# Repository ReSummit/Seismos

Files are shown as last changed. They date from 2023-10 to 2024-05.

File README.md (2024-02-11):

# Seismos

An evolution of the Zebra keyboard, but can be used for everyday typing. Switch between ortholinear for macro keypads and staggered for typing on the go.

Since this design utilizes daughter boards, you can even choose to move the columns around with a different rail system from the example one provided.

Allows for an interchangeable configuration between 4 and 5 row keys per column. With both halves of the keyboard, you can have a maximum of 68 keys (+2 encoder switches).

**NOTE:** If you had downloaded gerber files before December 5th, 2023, ***redownload*** the files as the RGB lights were not wired correctly. Apparently KiCAD displays the back side from the top perspective... doh! This is fixed. I also fixed the power switch so that sliding it up turns on the keyboard rather than this not being congruent on both sides.

## Pictures / Example Column Shifts:
<div style="display: flex; justify-content: center;">
    <figure>
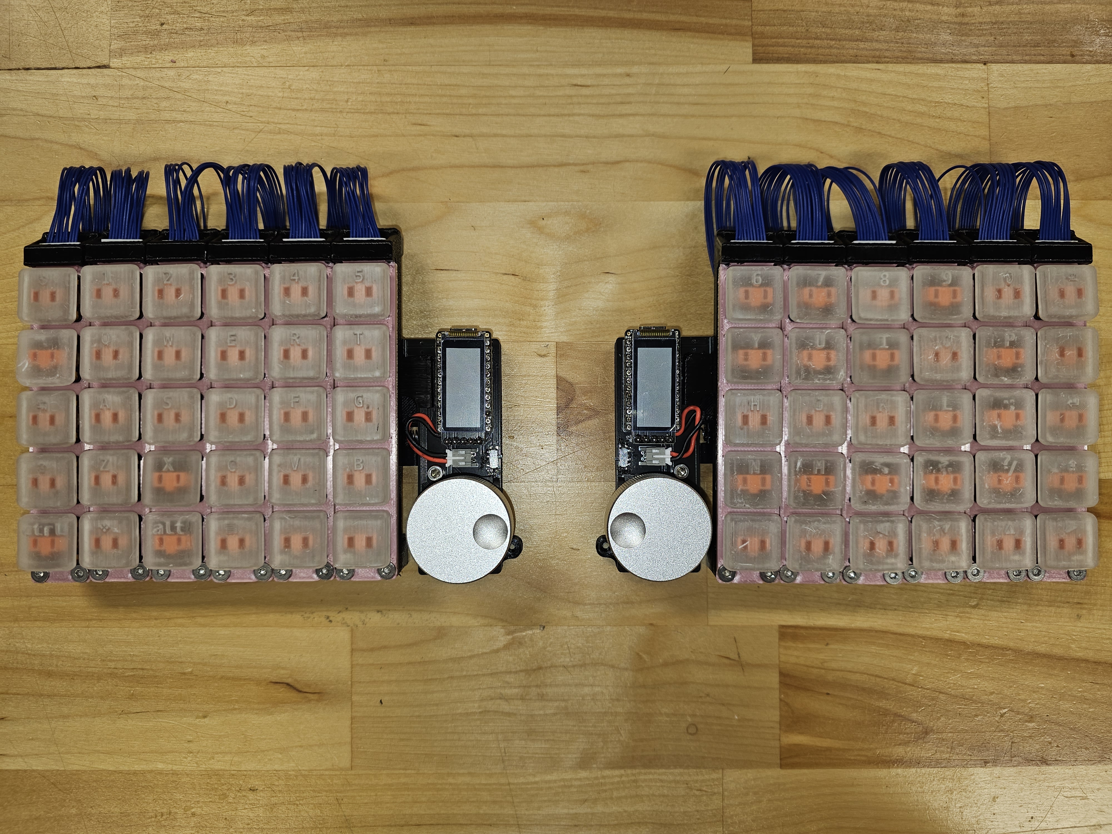
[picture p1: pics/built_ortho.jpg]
        
    </figure>
    <figure>
        
    </figure>
    <figure>
        
    </figure>
</div>

# PCB Library Structure

NOTE: If you check the PCB for DRC errors, most of them will come from either the keyboard_reversible.pretty footprint or the switch footprints inherited from the MiRage keyboard. Since both have been used before, they can be ignored.

## Libraries
All PCBs in the `pcbs` folder refer to the footprint and symbol libraries found in `libs/Seismos-libs` as well as `libs/keyboard_reversible.pretty`.

Wait, keyboard_reversible.pretty isn't in the git clone? You need to run git submodule initialization and update with this command:
```bash
git submodule update --init --recursive
```

After this, you should not get errors on missing libraries.

## Current State of PCBs
Since release v2.0.0, there are now PCBs that incorporate the 74HC595A shift register. Thanks to drFaustroll (from QMK Discord) on an example schematic for the shift register. With this shift register, displays are now on their own I2C / SPI bus and two pins are dedicated to split communications. 2 pins are now free so I have openned up these pins at the bottom of the keyboard on the front side. These ARE NOT compatible with the I2C variants of the keyboards unless you are not using the displays and will need some modification of the firmware, so choose carefully!

***WARNING***: If you are planning to use a display on this keyboard, note that nice!view compatibility with the I2C PCBs only applies for wireless builds only! Annoyingly, the nice!view does not use an ***I2C*** interface; it uses an ***SPI*** interface to work (***whyyyyyyy***). I considered moving the CS pin to the headphone jack, but this means that one of the hardware pins for I2C is not connected so this did not happen. Normal 4 pin I2C SSD1306 displays will work for wired or wireless builds however assuming that all communications happen on I2C.

There are column and thumb cluster layouts for 4 and 5 keys (however, thumb cluster can only have 4 max). This means you can get a max total of 68 keys, plus two if you are using the rotary encoders as buttons.

For this release, there are PCBs for 4 and 5 columns. Currently, the left, right, and columns are made with a maximum size of 7x5 keys per side. Something to know is that due to routing efficiency, the column order is reversed for the right side; however, row number remains the same from top to bottom.

With release v1.1.2, the PCBs are now fully tested and ready to be used. Still, read through the notes for building this keyboard a couple sections below so you know what you're getting into.

## PCB Design Thoughts
Theoretically, since JST SH connectors are pretty small, we can possibly a maximum of 12 pins, which means that you can get at most ~7 rows per column... if the microcontroller has that many pins!

Some future design thoughts:
* A suggestion to reduce pin count is to wire the 1x4 keys as a 2x2 key setup to save pins; however, this results in a 2x2n keyboard layout, which will likely be a pain... Still interesting though to point out.
* ZMK has a pull request that introduced charlieplexing, which will reduce the pin count. If this is done per half, it may be possible to have a 70% keyboard on both sides with 10 rows per column (5 forward diodes, 5 backwards diodes). There's quite a lot of room here but currently it is still in development.

# Important notes for building keyboard

For the JST SH cables, note that the male to male connector tips should face the same side. An example one is shown below (note it is a 9 pin JST SH cale, but should be the same for 10 pin JST cables).

Example of JST SH cable with male-to-male connectors facing the same side.
<div style="display: flex; justify-content: center;">
    <figure>
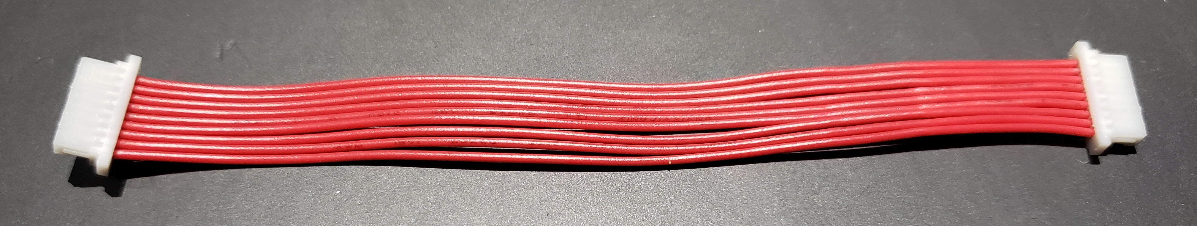
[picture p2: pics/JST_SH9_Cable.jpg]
        
    </figure>
</div>

Soldering the JST SH connectors is not easy! It is recommended to use the stencil design that is provided along with the stencil jig, hot plate, and solder paste. Otherwise, use a soldering iron and rely on flux!

After you are done building the core and mantle PCBs, there are example firmware files provided. Please checkout the `firmware_example` folder for more details. (Unfortunately, I haven't gotten to QMK yet, so that will have to wait for a bit)

# Required PCBs to upload

For PCBs, you will need the following:
* Minimum 2 core PCBs for left and right hands
* At least 14 mantle PCBs, 7 per core PCB
    * To save on cost, you may want to just stick with 20 of one type of mantle. 5 or 4 rows are usually enough

### **NOTE:** For the Core PCBs, you wil need to choose if you want I2C only or with a shift register starting from release v2.0.0. If you want to minimize components needed **and you are sure that you have an ATMEGA microcontroller**, you should choose I2C only. If you are not sure, you should choose I2C with shift register and just get the 74HC595A.

# BOM
## Required
* (**If using shift register version**) 2x 74HC595A SOIC-16 shift registers, though you may want extras just in case
* 28 x 10 position JST SH individual wires and connectors (preferrably 10cm long). Aliexpress has these with different colors like cable mods.
    * NOTE: For these links, they come from the same seller. Contact the seller after placing a temporary order to reduce shipping costs before paying!
    * Wires: https://www.aliexpress.us/item/3256802676433370.html (choose colors, **10 cm**, and **double head**)
        * For 5 rows, 10 cm is typically enough; you may be surprised at how far the columns can go with this. However, if you plan on changing the case design, you may need 15 cm if your columns need to go farther.
    * Connectors: https://www.aliexpress.us/item/3256802084257935.html (choose **10 pin** and **SMD Horizontal**)
* Parts that can be found from Typeractive.xyz:
    * 2 x EVQPUC02K reset button
    * 2 x SSSS811101 (alternatively on Aliexpress, MSK-12C01 or SW-12C01N-GY18)
    * 2 x 110 mAH battery (since TRRS does not have 5V, you need batteries; may change later)
* 2 x nice!nano (or Arduino Pro Micro compatible footprint)
* 56-70 x 1N4148W Diodes (variable number depending on how many keys you want)
* M3 assorted length screws (see case section for more details)
* 56-70 x MX / Choc PCB Sockets (1511 for MX or 1350 for Chocs)

## Optional
* 56-68 x SK6812MINI-E for RGB
    * 6 x per column from center of keyboard + 4 for each thumb cluster
        * Example: left and right sides require 80 total for all columns. If you only need 5 columns, then you need 68.
* 2 x nice!view (or OLED, but won't be aligned to center of microcontroller)
* 4 x 12 pin low profile socket pin headers for socketed microcontrollers (or similar)
* 2 x Rotary encoder EC11 (similar to Sofle)
* 2 x PJ320A headphone jacks 
    * **NOTE**: Due to me wanting to allow for wireless or wired setups, **the current PCB design will not charge the other keyboard side**. This is because VCC is disconnected to avoid blowing up the charging circuit of the nice!nano. If you need it, bridge the connector near one of the headphone jack pins.
* 2 x 4.7k SMD resistors for I2C. This is only needed if you plan on using I2C for split communications. There's not enough space for THT versions so uh sorry :(.

# Case
Curious to see what it looks like? Behold, OnShape link that contains questionable features that are unlabelled... This case works with the PCBs and allows for sliding rails, but won't lock the rails. A better design is in the works, but this is a good start.

Currently, a better design is in the works to place the rails underneath the PCB instead of above; this would allow the keyboard to be more low profile. For now, this works.

**This design requires the following additional parts:**
* Countersunk M3 screws:
    * 24 M3x12mm
        * Mounts down the PCB to each column plate frame into the bottom stopper
    * 3 M3x8mm
        * Holds down the rails for the keyboard
    * 14 M3x6mm
        * Corresponding nuts for the top stopper screws located near the top of each column needed
    * 2 M3x5mm
        * For the holes near the encoder and display

<p align="center">
    <p>Onshape Document (click on picture):</p>
    <a href="https://cad.onshape.com/documents/f7367bff9cd2cc9be8d2436b/w/1f753fadbcf1b9049e256121/e/c4b472236e977df85b7d8a49">
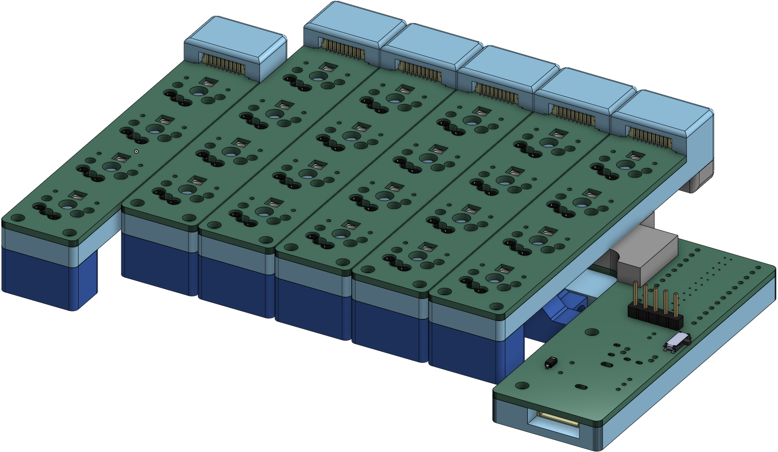
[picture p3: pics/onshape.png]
OnShape
        
    </a>
</p>

# More Pictures
<div style="display: flex; justify-content: center;">
    More pictures of build:
    <figure>
        
    </figure>
    <figure>
        
    </figure>
    Development case design:
    <figure>
        
    </figure>
    <figure>
        
    </figure>
</div>

# References

Seismos uses elements found from multiple places for footprints, symbols, and even the idea.

The idea for this keyboard was inspired from the [Zebra keyboard](https://github.com/nezumee/zebra). It uses jumper cables but looks to be mainly for having a physical means to determine the layout.

For footprints, they are derived from multiple places:
* [SnapEDA](https://snapeda.com) for initial 9 position JST SH footprints and models.
* [EasyEDA](https://easyeda.com) for the power switch, reset button, and 10 position JST SH footprints as well as some models.
* [Corne](https://github.com/foostan/crkbd) repository for the SK6812MINI-E footprint.
    * Fork from [petejohanson](https://github.com/petejohanson/crkbd/tree/board/corne-ultralight) for guide on nice!view pin connections.
* [Sofle](https://github.com/josefadamcik/SofleKeyboard) keyboard for rotary encoder and headphone jack footprints.
    * [Hayden Hu's PJ320A model](https://grabcad.com/library/pj320a-pj320d-3-5mm-jack-10) was used to show the headphone jack on the 3D viewer.
    * [Dmitry Levin's EC11 encoder models](https://grabcad.com/library/11mm-metal-shaft-rotary-encoders-tht-vertical-w-push-on-switch-1) was used to show the encoder on the 3D viewer.
* [keyboard_reversible.pretty](https://github.com/50an6xy06r6n/keyboard_reversible.pretty) for easy reverse footprints made for the Pro Micro.
* [Zack Freedman's MiRage Keyboard](https://github.com/ZackFreedman/MiRage) for Choc / MX footprints with modifications to include SK6812MINI-E within the footprint.
    * [Dennis Lee's Kailh 1350 socket model](https://grabcad.com/library/kailh-1350-socket-20) was used to show the switch socket on the 3D viewer.

In the libs folder, there may be other files regarding other footprints such as the EVQPUC02K. This was found on EasyEDA on early attempts to extract the footprints.
There is also the MSK-12C02 switch. This was found from [mzst's blog](https://mzstblog.blogspot.com/2016/01/msk-12c02-smd-slider-switch-spdt-eagle.html) website, which was a good reference for the switch, but I ended up using the symbol and combined with the other footprint found from EasyEDA. Archived here as well bvecause it is nice to have a backup of it.

For firmware, there are QMK, ZMK, and KMK. Only QMK has support for shift registers at the moment but I will get to the other firmwares at some point. QMK's firmware is somewhat based from the Sofle code already on the qmk_firmware, especially the oled implementation, which is untested. Also, the LICENSE may need to be updated; will check this later.

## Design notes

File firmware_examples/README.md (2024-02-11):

# Firmware files for Seismos
If you are finished with your PCB, congratulations! The PCBs are quite a challenge to do; I would know doing the PCBs twice at the moment...

**NOTE**: As of now, since the shift register was introduced in v2.0.0, only QMK has it configured. I will get to KMK and ZMK later but for now, they serve as an okay example for the column and keycode layout.

At this point, you can now flash your firmware to your Seismos. Here, you can find two firmware files for Seismos:
* KMK
    * KMK requires the normal setup for installing into your microcontroller. If you have chosen to use RGB, you will also need to import the neopixel library from adafruit into the `lib` folder. If you don't need this, remove the RGB sections from `main.py`. After that, you should be good to go with a basic layout.
* ZMK
    * ZMK requires a compilation of the firmware. Here, files are provided for a nice!nano v2 with a nice!view display. Follow the initialization steps to setup ZMK. Then copy the folder inside the zmk folder into `app/boards/shields`. You can then compile with the following code. If you have a zmk-config folder, use the flag `-DZMK_CONFIG="<zmk-config folder>"`:
```bash
west build --pristine -d build/seismosL -b nice_nano_v2 -- -DSHIELD="seismos_left nice_view_adapter nice_view"
cp build/seismosL/zephyr/zmk.uf2 ./seismosL.uf2

west build --pristine -d build/seismosR -b nice_nano_v2 -- -DSHIELD="seismos_right nice_view_adapter nice_view"
cp build/seismosR/zephyr/zmk.uf2 ./seismosR.uf2
```
    * Unfortunately, I haven't gotten to compile this for the RP2040. If you happen to get that working, do a pull request and I can take a look.
* QMK
    * QMK firmware uses some code from Sofle's QMK codebase, especially the oled (untested)
    * The current QMK firmware uploaded uses RP2040 conversion for the RP2040 board I have. If you have a pro micro, you can disable this conversion in the `rules.mk` file.

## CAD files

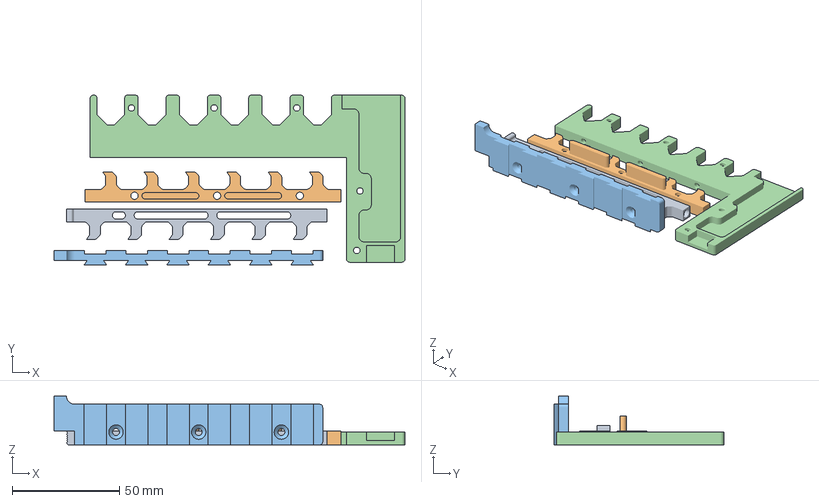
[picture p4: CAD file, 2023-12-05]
3dmodels/case/Mantle/Mantle.3mf
163.9 x 79.2 x 22.8 mm
Mantle - Part 4.stl
Mantle - Part 3.stl
Mantle - Part 2.stl
Mantle - Part 1.stl

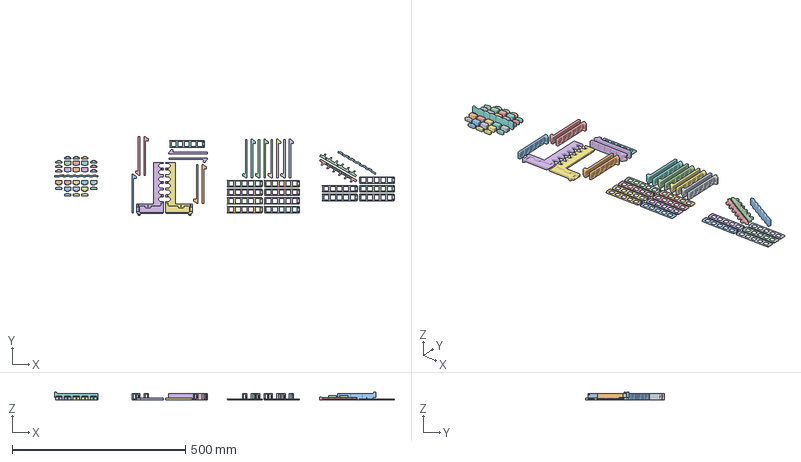
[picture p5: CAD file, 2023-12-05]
3dmodels/case/Plate/Plate_Mantle.3mf
981.2 x 229.0 x 22.8 mm
Plate - Part 4.stl
Plate - Part 2.stl
Plate - Part 3.stl
Plate - Part 1.stl
Plate Optimal
Mantle - Part 2.stl x 2
Mantle - Part 3.stl
Mantle - Part 4.stl
Mantle - Part 1.stl x 2

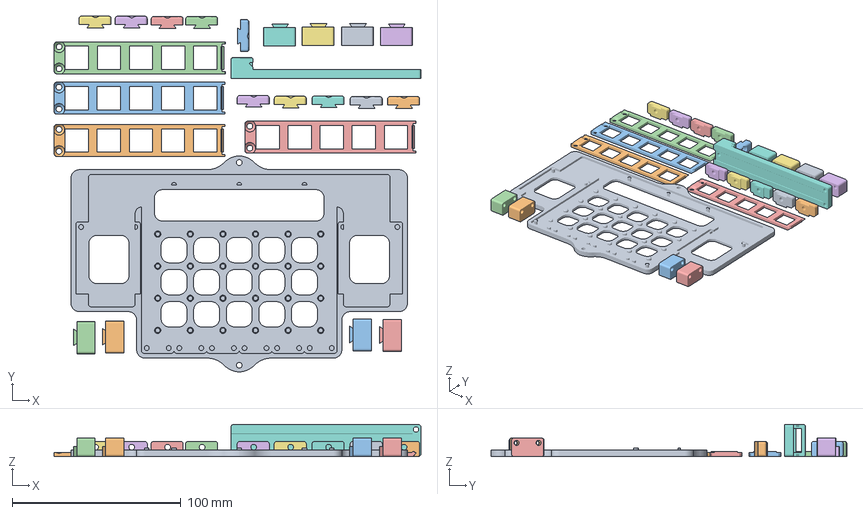
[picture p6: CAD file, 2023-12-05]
3dmodels/case/Stencil Jig - Part 1.3mf
217.2 x 210.7 x 19.0 mm
Stencil Jig - Part 1.stl
Plate - 5 Key - Part 4.stl
Plate - 5 Key - Part 3.stl
Plate - 5 Key - Part 2.stl
Plate - 5 Key - Part 1.stl

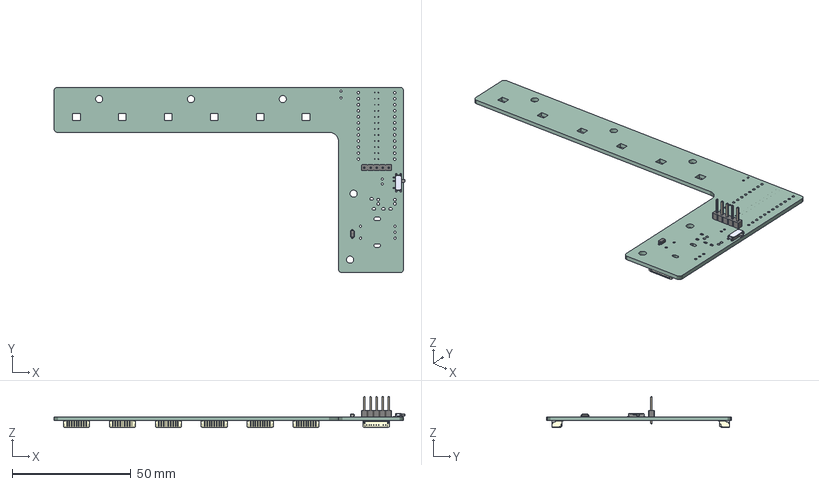
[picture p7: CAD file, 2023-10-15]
3dmodels/pcb/Seismos_CoreL.step
147.6 x 78.0 x 13.1 mm
Seismos_CoreL PCB

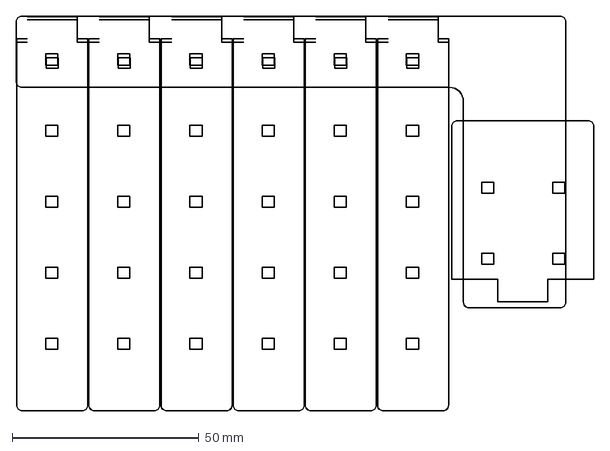
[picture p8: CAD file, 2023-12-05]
pcbs/Core PCBs (Mantles)/Stencil/Seismos_5CoreStencil/svg/Seismos_5CoreStencil-Edge_Cuts.dxf
154.5 x 105.5 mm

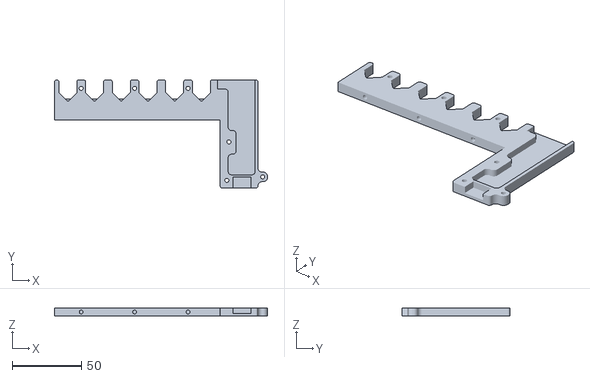
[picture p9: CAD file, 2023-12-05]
3dmodels/case/Mantle/Mantle - Part 1.stl
153.9 x 78.0 x 6.00

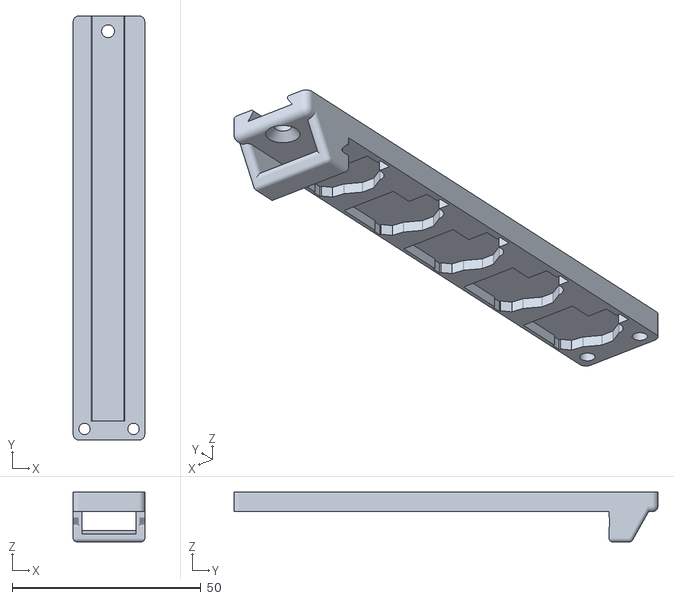
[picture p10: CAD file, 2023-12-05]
3dmodels/case/Plate/Plate - Part 1.stl
19.0 x 112.4 x 13.2

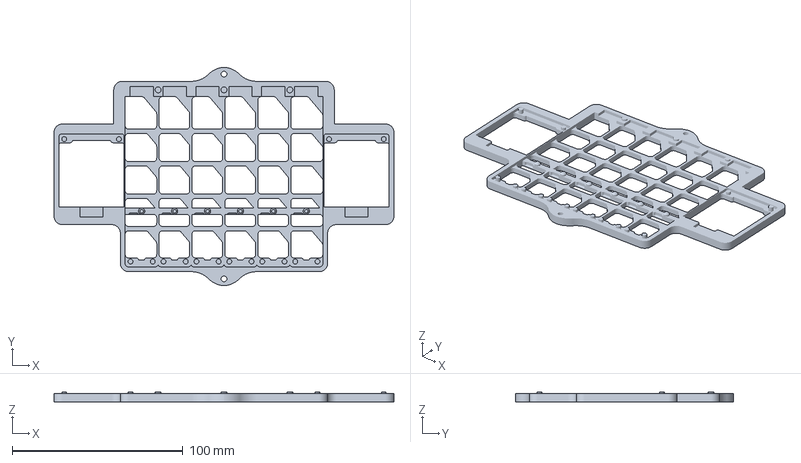
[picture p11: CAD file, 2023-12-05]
3dmodels/case/Stencil Jig Front - Part 1.3mf
199.2 x 128.0 x 6.00 mm

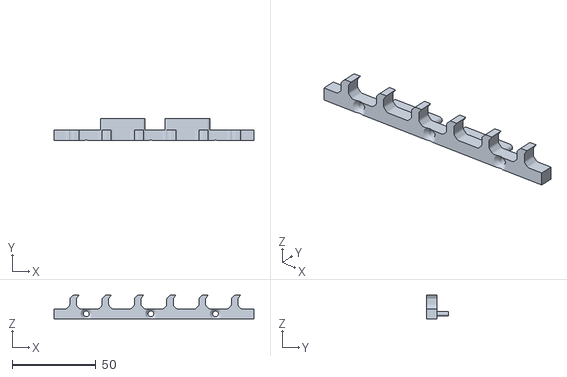
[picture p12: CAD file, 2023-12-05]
3dmodels/case/Mantle/Mantle - Part 3.stl
119.5 x 13.4 x 14.2

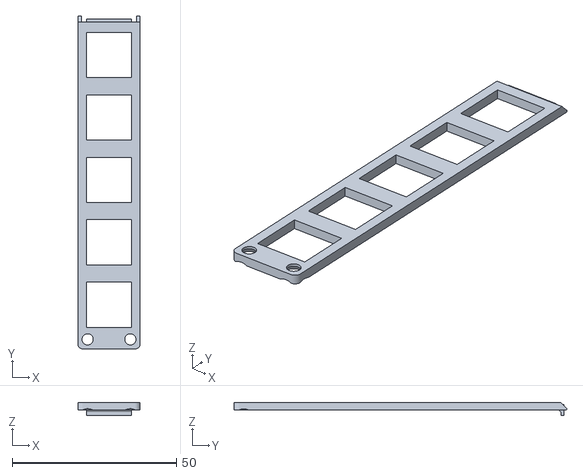
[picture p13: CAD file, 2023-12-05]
3dmodels/case/Plate/Plate - Part 4.stl
19.0 x 101.3 x 3.95

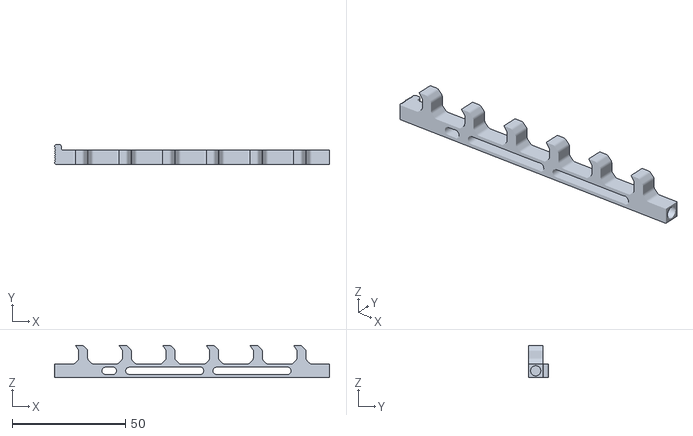
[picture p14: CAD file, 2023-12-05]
3dmodels/case/Mantle/Mantle - Part 4.stl
121.6 x 9.00 x 14.2

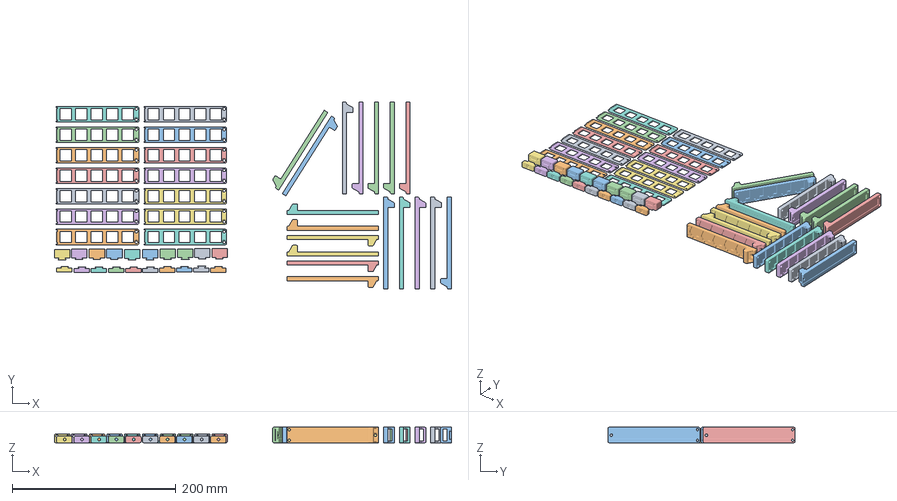
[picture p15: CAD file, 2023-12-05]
3dmodels/case/Plate/Plate.3mf
485.5 x 228.8 x 19.0 mm
Plate - Part 2.stl
Plate - Part 3.stl
Plate - Part 4.stl
Plate - Part 1.stl

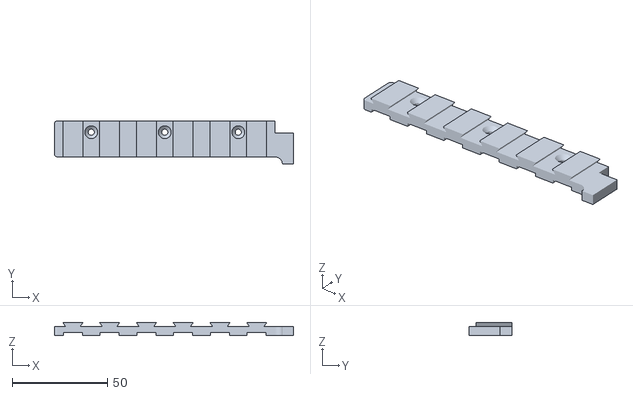
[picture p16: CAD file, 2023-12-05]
3dmodels/case/Mantle/Mantle - Part 2.stl
125.5 x 22.8 x 6.62

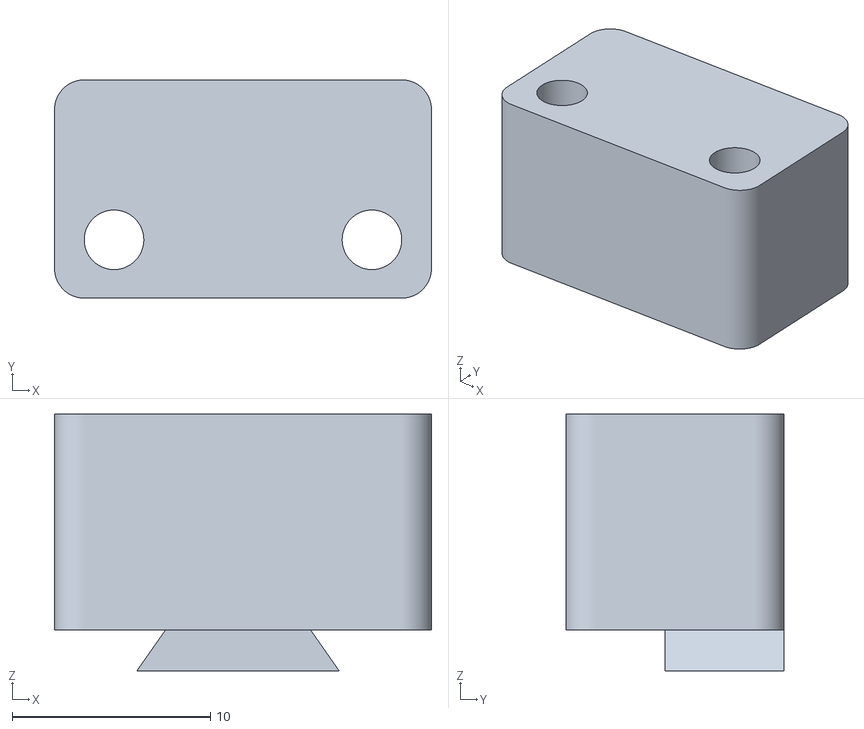
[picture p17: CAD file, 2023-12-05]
3dmodels/case/Plate/Plate - Part 3.stl
19.0 x 11.0 x 12.9

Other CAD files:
3dmodels/case/Plate/Plate_Rails.3mf
3dmodels/case/Plate/Plate - Part 2.stl
3dmodels/case/Stencil Jig - Part 1.stl
3dmodels/case/Stencil Jig Front - Part 1.stl
pcbs/Core PCBs (Mantles)/Stencil/Seismos_5CoreStencil/svg/Seismos_5CoreStencil-F_Mask.dxf
pcbs/Core PCBs (Mantles)/Stencil/Seismos_5CoreStencil/svg/Seismos_5CoreStencil-F_Paste.dxf

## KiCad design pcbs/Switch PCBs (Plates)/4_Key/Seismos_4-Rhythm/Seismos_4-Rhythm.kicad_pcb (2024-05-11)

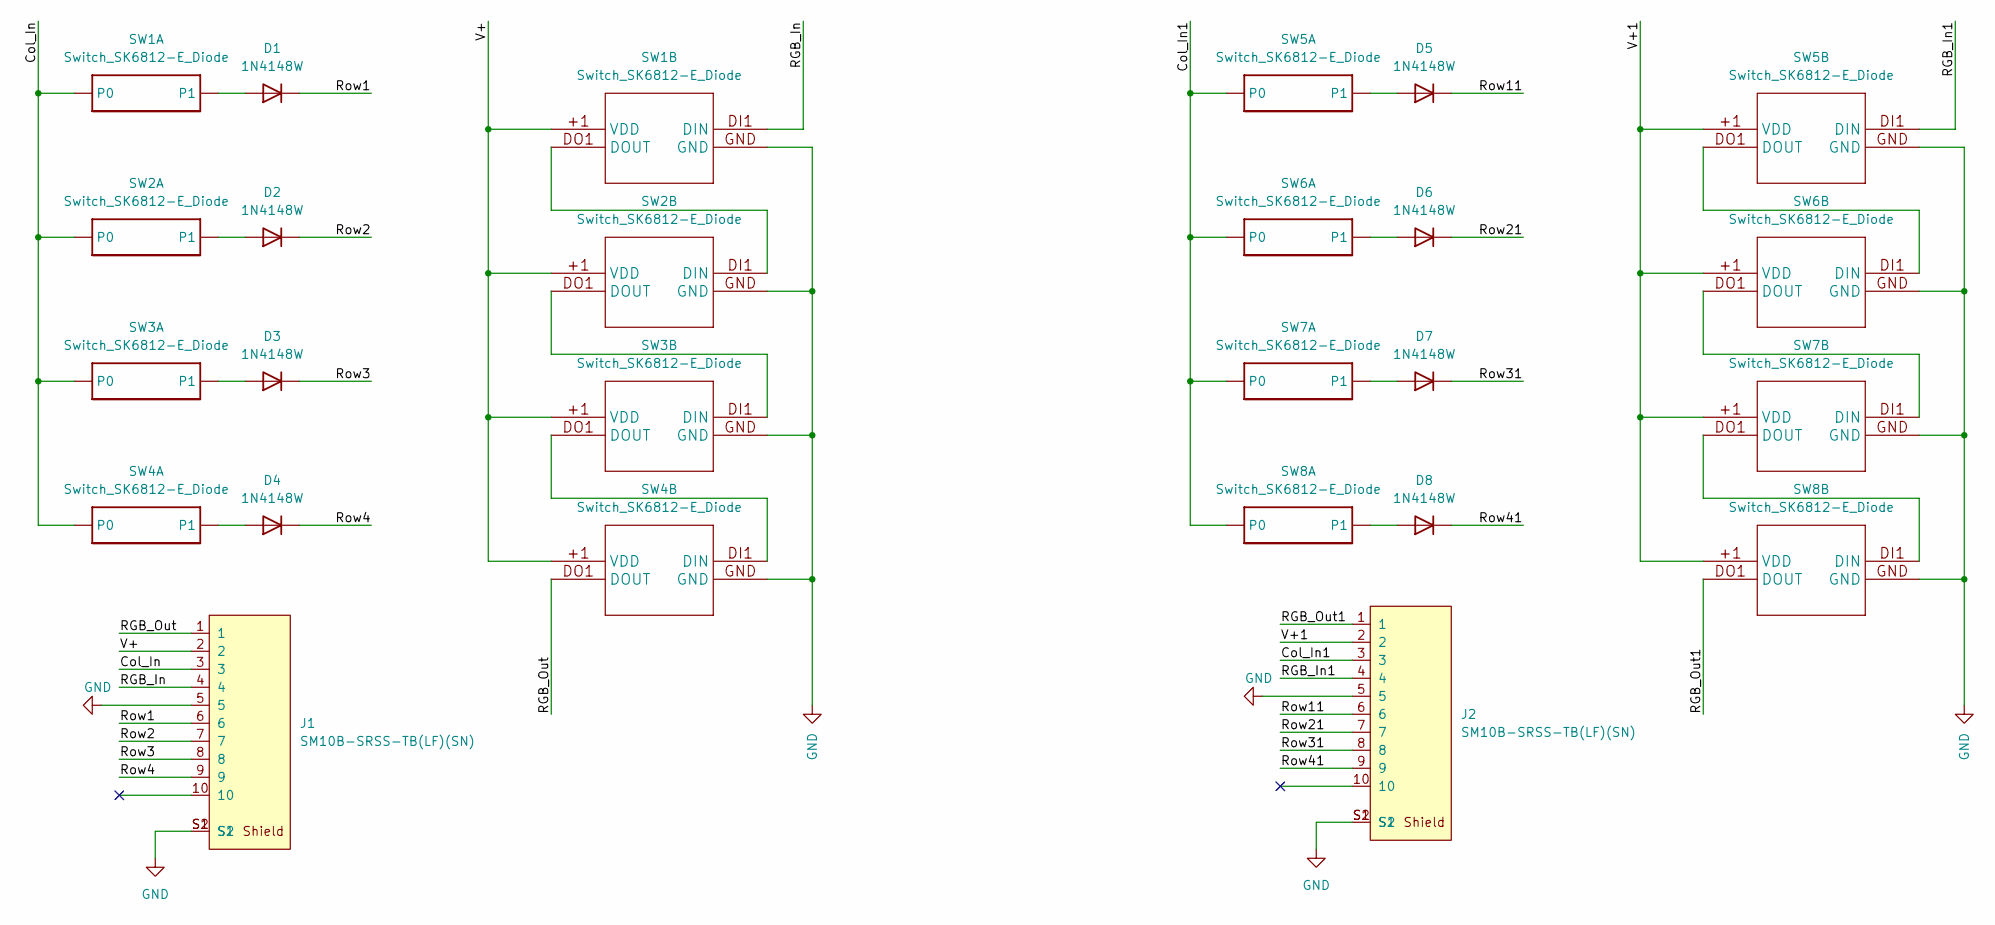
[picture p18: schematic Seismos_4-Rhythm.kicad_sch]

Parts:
D1, D2, D3, D4, D5, D6, D7, D8: 1N4148W; D_SOD-123
J1, J2: SM10B-SRSS-TB(LF)(SN); CONN-SMD_10P-P1.00_SM10B-SRSS-TB-LF-SN; PARTREV 1.0
SW1, SW2, SW3, SW4, SW5, SW6, SW7, SW8: Switch_SK6812-E_Diode

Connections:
/Col_In: J1.3, SW1.CHOC2 (P0), SW1.MX2 (P0), SW2.CHOC2 (P0), SW2.MX2 (P0), SW3.CHOC2 (P0), SW3.MX2 (P0), SW4.CHOC2 (P0), SW4.MX2 (P0)
/Col_In1: J2.3, SW5.CHOC2 (P0), SW5.MX2 (P0), SW6.CHOC2 (P0), SW6.MX2 (P0), SW7.CHOC2 (P0), SW7.MX2 (P0), SW8.CHOC2 (P0), SW8.MX2 (P0)
/RGB_In: J1.4, SW1.DI1 (DIN)
/RGB_In1: J2.4, SW5.DI1 (DIN)
/RGB_Out: J1.1, SW4.DO1 (DOUT)
/RGB_Out1: J2.1, SW8.DO1 (DOUT)
/Row1: D1.1 (K), J1.6
/Row2: D2.1 (K), J1.7
/Row3: D3.1 (K), J1.8
/Row4: D4.1 (K), J1.9
/Row11: D5.1 (K), J2.6
/Row21: D6.1 (K), J2.7
/Row31: D7.1 (K), J2.8
/Row41: D8.1 (K), J2.9
/V+: J1.2, SW1.+1 (VDD), SW2.+1 (VDD), SW3.+1 (VDD), SW4.+1 (VDD)
/V+1: J2.2, SW5.+1 (VDD), SW6.+1 (VDD), SW7.+1 (VDD), SW8.+1 (VDD)
GND: J1.5, J1.S1, J1.S2, J2.5, J2.S1, J2.S2, SW1.GND, SW2.GND, SW3.GND, SW4.GND, SW5.GND, SW6.GND, SW7.GND, SW8.GND
unnamed: D1.2 (A), SW1.CHOC1 (P1), SW1.MX1 (P1)
unnamed: D2.2 (A), SW2.CHOC1 (P1), SW2.MX1 (P1)
unnamed: D3.2 (A), SW3.CHOC1 (P1), SW3.MX1 (P1)
unnamed: D4.2 (A), SW4.CHOC1 (P1), SW4.MX1 (P1)
unnamed: D5.2 (A), SW5.CHOC1 (P1), SW5.MX1 (P1)
unnamed: D6.2 (A), SW6.CHOC1 (P1), SW6.MX1 (P1)
unnamed: D7.2 (A), SW7.CHOC1 (P1), SW7.MX1 (P1)
unnamed: D8.2 (A), SW8.CHOC1 (P1), SW8.MX1 (P1)
unnamed: SW1.DO1 (DOUT), SW2.DI1 (DIN)
unnamed: SW2.DO1 (DOUT), SW3.DI1 (DIN)
unnamed: SW3.DO1 (DOUT), SW4.DI1 (DIN)
unnamed: SW5.DO1 (DOUT), SW6.DI1 (DIN)
unnamed: SW6.DO1 (DOUT), SW7.DI1 (DIN)
unnamed: SW7.DO1 (DOUT), SW8.DI1 (DIN)

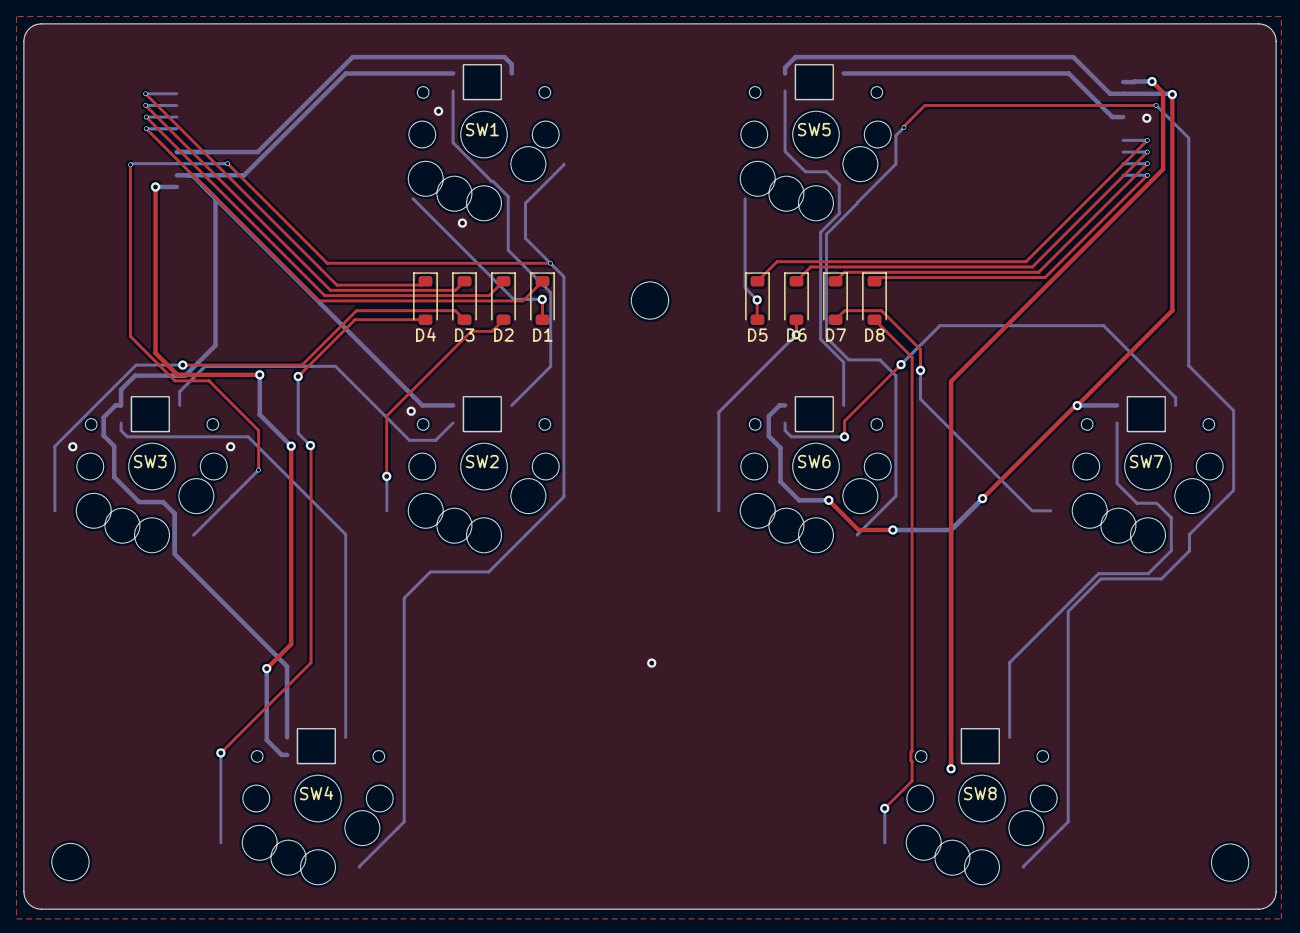
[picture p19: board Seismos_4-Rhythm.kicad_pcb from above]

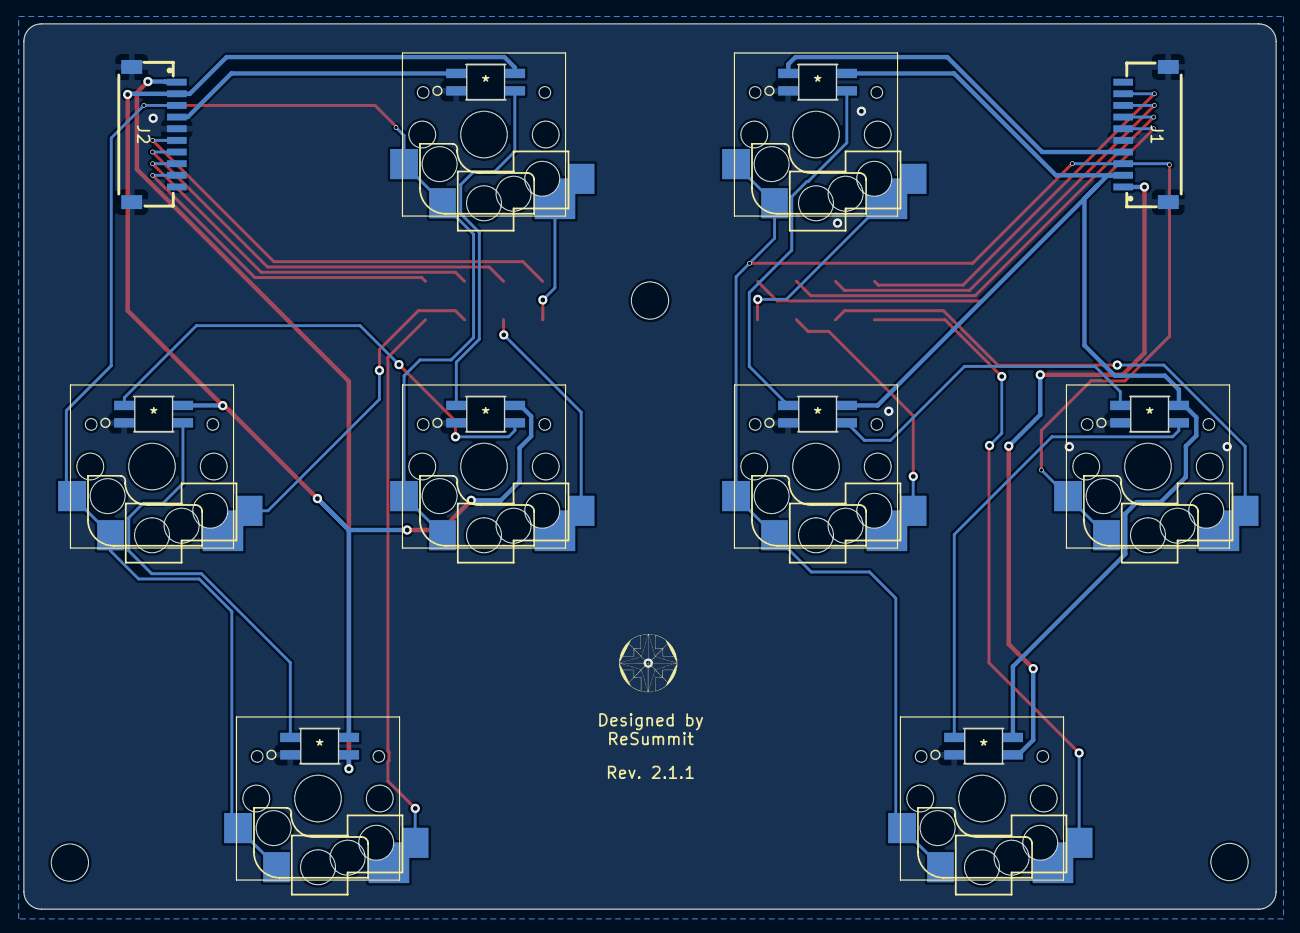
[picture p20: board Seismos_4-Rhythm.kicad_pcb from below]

Board: 2 copper layers, 107.5 x 76.0 mm, 18 parts (10 on the bottom side), 31 nets.

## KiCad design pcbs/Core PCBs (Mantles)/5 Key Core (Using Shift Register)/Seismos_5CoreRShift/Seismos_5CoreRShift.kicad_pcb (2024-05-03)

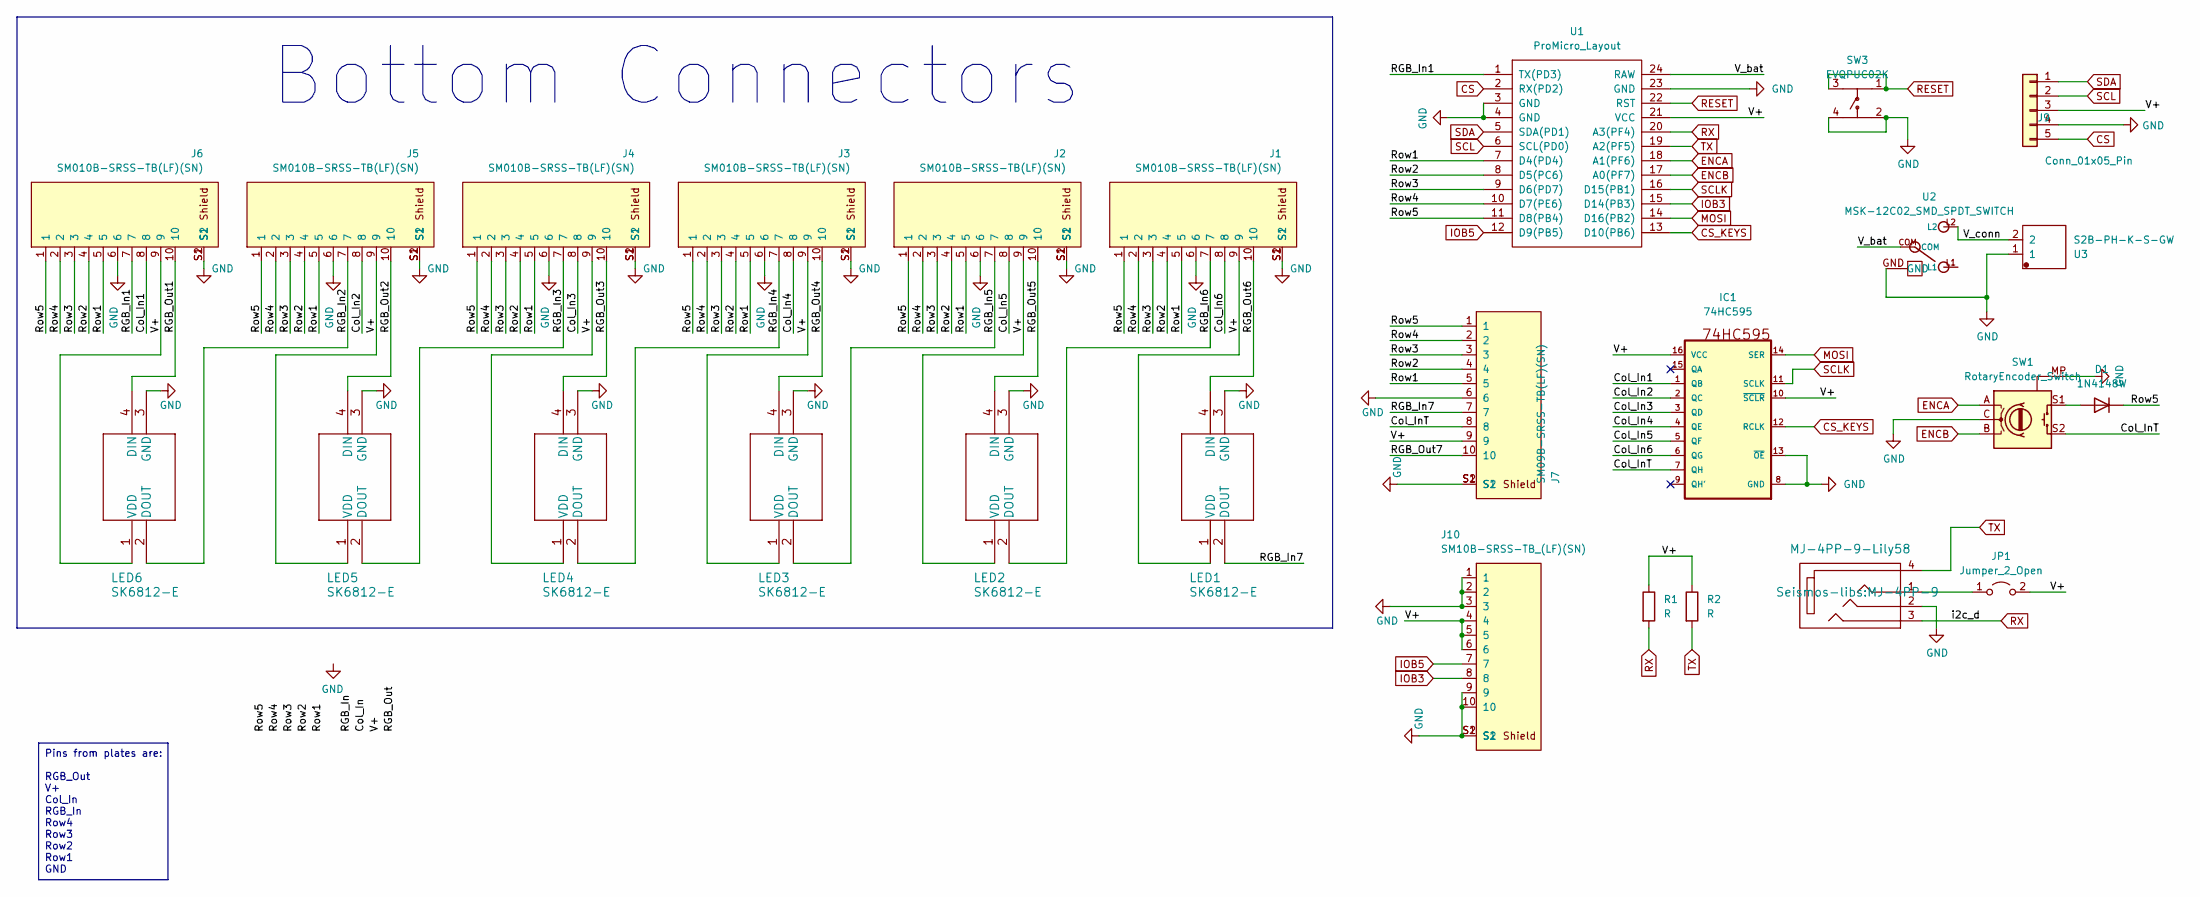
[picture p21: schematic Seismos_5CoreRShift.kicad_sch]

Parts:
D1: 1N4148W; D_SOD-123
IC1: 74HC595; SO16
J1, J2, J3, J4, J5, J6: SM010B-SRSS-TB(LF)(SN); CONN-SMD_10P-P1.00_SM10B-SRSS-TB-LF-SN; PARTREV 1.0
J7: SM09B-SRSS-TB(LF)(SN); CONN-SMD_10P-P1.00_SM10B-SRSS-TB-LF-SN; PARTREV 1.0
J8: MJ-4PP-9-Lily58; MJ-4PP-9
J9: Conn_01x05_Pin; PinHeader_1x05_P2.54mm_Vertical
J10: SM10B-SRSS-TB_(LF)(SN); CONN-SMD_10P-P1.00_SM10B-SRSS-TB-LF-SN; PARTREV 1.0
JP1: Jumper_2_Open; SolderJumper-2_P1.3mm_Open_TrianglePad1.0x1.5mm
LED1, LED2, LED3, LED4, LED5, LED6: SK6812-E
R1, R2: R; R_0603_1608Metric_Pad0.98x0.95mm_HandSolder
SW1: RotaryEncoder_Switch; RotaryEncoder_Alps_EC11E-Switch_Vertical_H20mm-keebio_modif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
SW3: EVQPUC02K; SW-SMD_EVQPUD02K
U1: ProMicro_Layout; keebRev-onesided_ProMicro
U2: MSK-12C02_SMD_SPDT_SWITCH; SW_PCM12SMTR
U3: S2B-PH-K-S-GW; CONN-TH_S2B-PH-K-S-GW

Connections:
/Col_In1: IC1.1 (QB), J6.8
/Col_In2: IC1.2 (QC), J5.8
/Col_In3: IC1.3 (QD), J4.8
/Col_In4: IC1.4 (QE), J3.8
/Col_In5: IC1.5 (QF), J2.8
/Col_In6: IC1.6 (QG), J1.8
/Col_InT: IC1.7 (QH), J7.8, SW1.S2
/RGB_In1: J6.7, U1.1 (TX(PD3))
/RGB_In2: J5.7, LED6.2 (DOUT)
/RGB_In3: J4.7, LED5.2 (DOUT)
/RGB_In4: J3.7, LED4.2 (DOUT)
/RGB_In5: J2.7, LED3.2 (DOUT)
/RGB_In6: J1.7, LED2.2 (DOUT)
/RGB_In7: J7.7, LED1.2 (DOUT)
/RGB_Out1: J6.10, LED6.4 (DIN)
/RGB_Out2: J5.10, LED5.4 (DIN)
/RGB_Out3: J4.10, LED4.4 (DIN)
/RGB_Out4: J3.10, LED3.4 (DIN)
/RGB_Out5: J2.10, LED2.4 (DIN)
/RGB_Out6: J1.10, LED1.4 (DIN)
/RGB_Out7: J7.10
/Row1: J1.5, J2.5, J3.5, J4.5, J5.5, J6.5, J7.5, U1.7 (D4(PD4))
/Row2: J1.4, J2.4, J3.4, J4.4, J5.4, J6.4, J7.4, U1.8 (D5(PC6))
/Row3: J1.3, J2.3, J3.3, J4.3, J5.3, J6.3, J7.3, U1.9 (D6(PD7))
/Row4: J1.2, J2.2, J3.2, J4.2, J5.2, J6.2, J7.2, U1.10 (D7(PE6))
/Row5: D1.1 (K), J1.1, J2.1, J3.1, J4.1, J5.1, J6.1, J7.1, U1.11 (D8(PB4))
/V+: IC1.10 (~SCLR), IC1.16 (VCC), J1.9, J2.9, J3.9, J4.9, J5.9, J6.9, J7.9, J9.3, J10.4, J10.5, J10.6, JP1.2 (B), LED1.1 (VDD), LED2.1 (VDD), LED3.1 (VDD), LED4.1 (VDD), LED5.1 (VDD), LED6.1 (VDD), R1.1, R2.1, U1.21 (VCC)
/V_bat: U1.24 (RAW), U2.COM
/V_conn: U2.L2, U3.2
CS: J9.5, U1.2 (RX(PD2))
CS_KEYS: IC1.12 (RCLK), U1.13 (D10(PB6))
ENCA: SW1.A, U1.18 (A1(PF6))
ENCB: SW1.B, U1.17 (A0(PF7))
GND: IC1.8 (GND), IC1.13 (~OE), J1.6, J1.S1, J1.S2, J2.6, J2.S1, J2.S2, J3.6, J3.S1, J3.S2, J4.6, J4.S1, J4.S2, J5.6, J5.S1, J5.S2, J6.6, J6.S1, J6.S2, J7.6, J7.S1, J7.S2, J8.2, J9.4, J10.1, J10.2, J10.3, J10.9, J10.10, J10.S1, J10.S2, LED1.3 (GND), LED2.3 (GND), LED3.3 (GND), LED4.3 (GND), LED5.3 (GND), LED6.3 (GND), SW1.C, SW1.MP, SW3.2, SW3.4, U1.3 (GND), U1.4 (GND), U1.23 (GND), U2.GND, U3.1
IOB3: J10.8, U1.15 (D14(PB3))
IOB5: J10.7, U1.12 (D9(PB5))
MOSI: IC1.14 (SER), U1.14 (D16(PB2))
unnamed: D1.2 (A), SW1.S1
unnamed: J8.1, JP1.1 (A)
RESET: SW3.1, SW3.3, U1.22 (RST)
RX: J8.3, R1.2, U1.20 (A3(PF4))
SCL: J9.2, U1.6 (SCL(PD0))
SCLK: IC1.11 (SCLK), U1.16 (D15(PB1))
SDA: J9.1, U1.5 (SDA(PD1))
TX: J8.4, R2.2, U1.19 (A2(PF5))

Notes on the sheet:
Pins from plates are: RGB_Out V+ Col_In RGB_In Row4 Row3 Row2 Row1 GND
Bottom Connectors

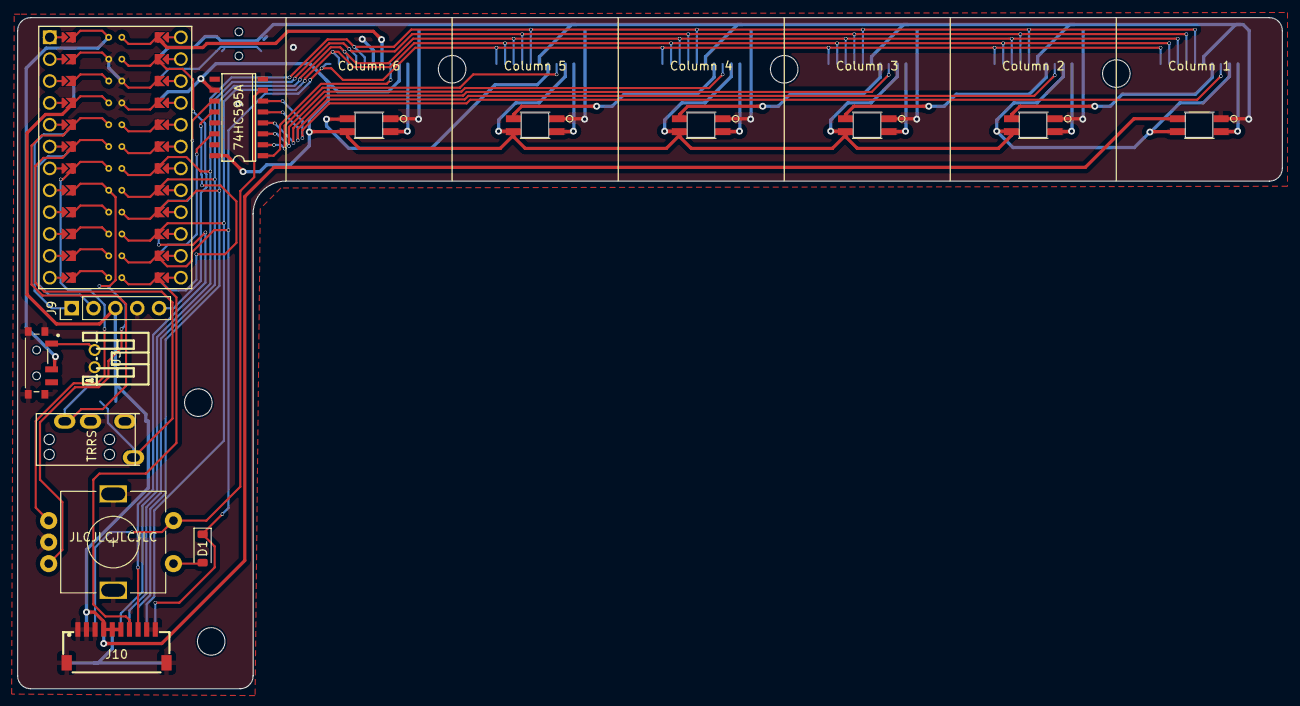
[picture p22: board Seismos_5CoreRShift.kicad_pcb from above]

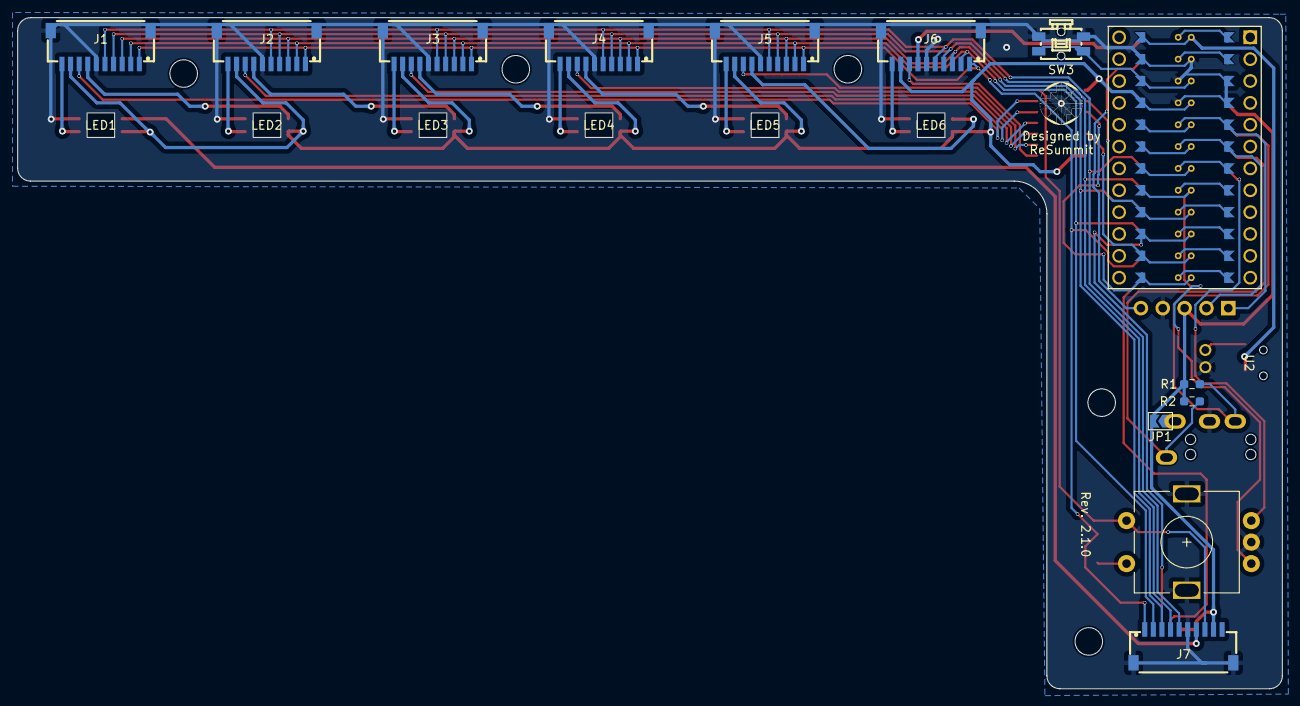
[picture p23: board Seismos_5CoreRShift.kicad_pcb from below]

Board: 2 copper layers, 147.0 x 78.0 mm, 26 parts (11 on the bottom side), 44 nets.

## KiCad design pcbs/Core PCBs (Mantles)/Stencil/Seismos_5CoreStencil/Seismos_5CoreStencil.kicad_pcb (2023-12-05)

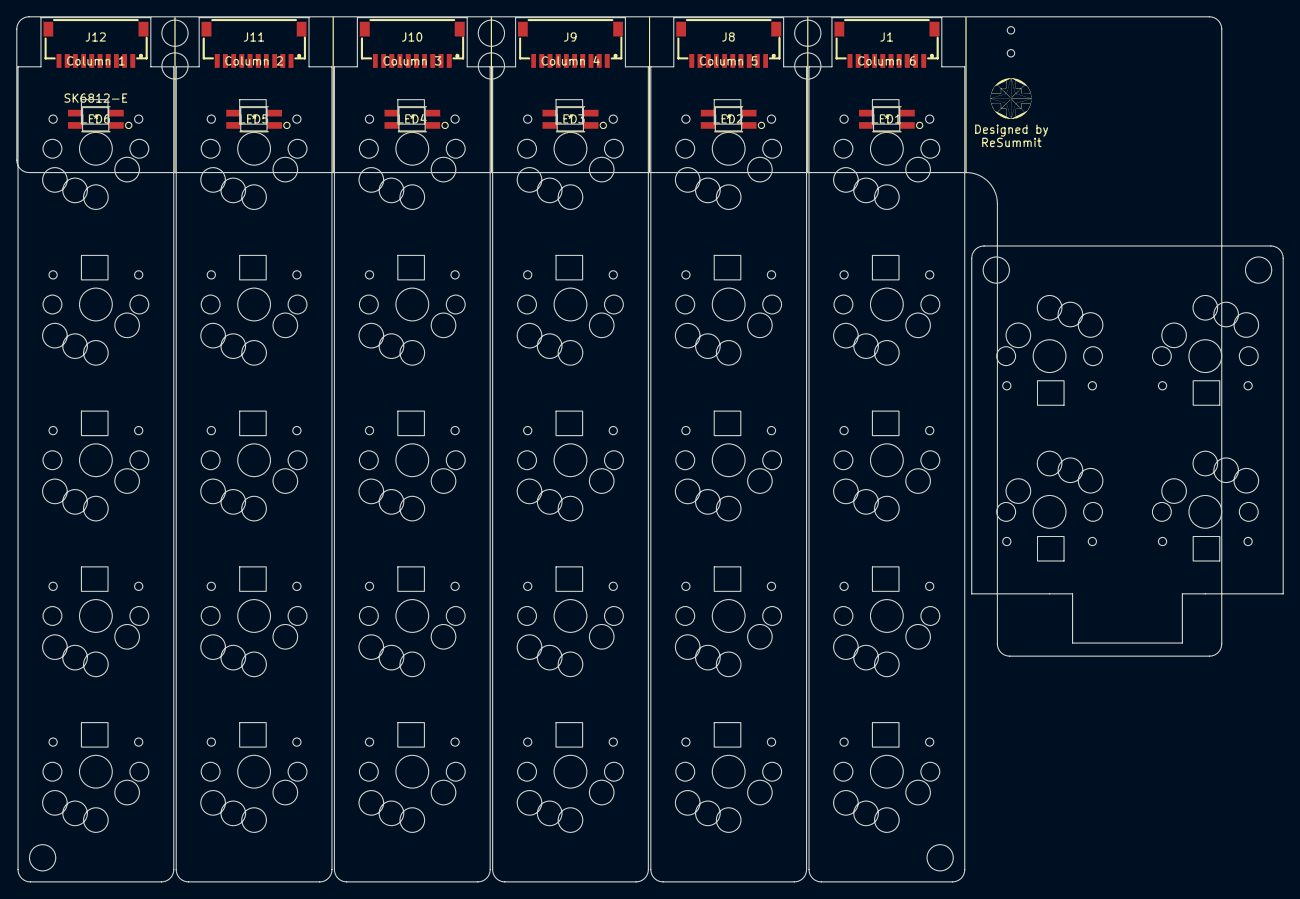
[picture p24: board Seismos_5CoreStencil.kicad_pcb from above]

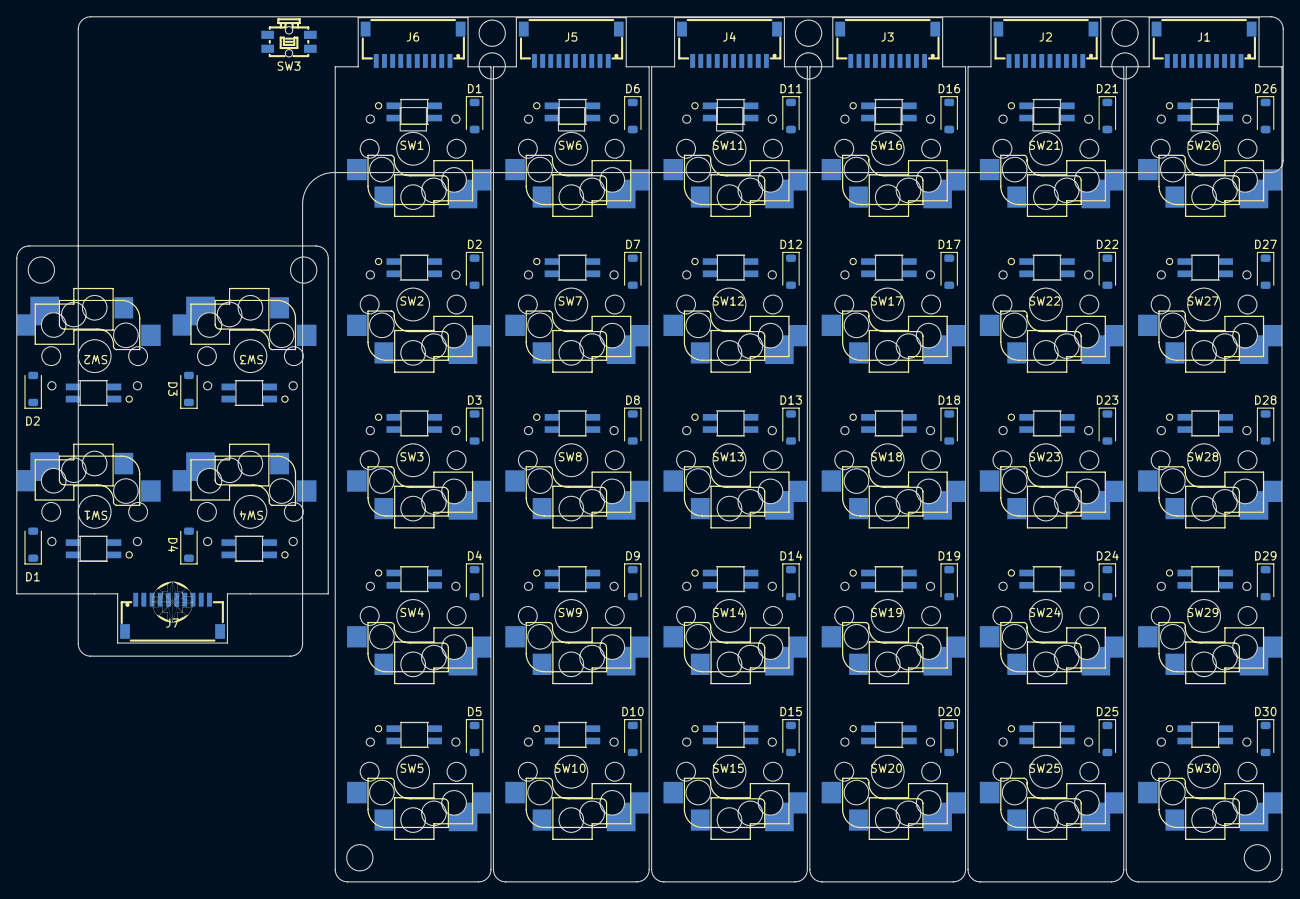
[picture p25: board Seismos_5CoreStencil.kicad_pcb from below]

Board: 2 copper layers, 154.5 x 105.5 mm, 91 parts (82 on the bottom side), 20 nets, no tracks yet.

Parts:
2, 4, 4#2: Hole_M3_3.2mm
D1, D1#2, D2, D2#2, D3, D3#2, D4, D4#2, D5, D6, D7, D8, D9, D10, D11, D12, D13, D14, D15, D16, D17, D18, D19, D20, D21, D22, D23, D24, D25, D26, D27, D28, D29, D30: 1N4148W; D_SOD-123
J1, J8, J9, J10, J11, J12: SM10B-SRSS-TB_(LF)(SN); CONN-SMD_10P-P1.00_SM10B-SRSS-TB-LF-SN
J1#2, J2, J3, J4, J5, J6, J7: SM09B-SRSS-TB(LF)(SN); CONN-SMD_10P-P1.00_SM10B-SRSS-TB-LF-SN
LED1, LED2, LED3, LED4, LED5, LED6: SK6812-E
SW1, SW1#2, SW2, SW2#2, SW3, SW3#3, SW4, SW4#2, SW5, SW6, SW7, SW8, SW9, SW10, SW11, SW12, SW13, SW14, SW15, SW16, SW17, SW18, SW19, SW20, SW21, SW22, SW23, SW24, SW25, SW26, SW27, SW28, SW29, SW30: Switch_SK6812-E_Diode
SW3#2: EVQPUC02K; SW-SMD_EVQPUD02K

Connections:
/RGB_In2: J5.7, LED1.2 (DOUT)
/RGB_In3: J4.7, LED2.2 (DOUT)
/RGB_In4: J3.7, LED3.2 (DOUT)
/RGB_In5: J2.7, LED4.2 (DOUT)
/RGB_In6: J1#2.7, LED5.2 (DOUT)
/RGB_In7: J7.7, LED6.2 (DOUT)
/RGB_Out1: J6.10, LED1.4 (DIN)
/RGB_Out2: J5.10, LED2.4 (DIN)
/RGB_Out3: J4.10, LED3.4 (DIN)
/RGB_Out4: J3.10, LED4.4 (DIN)
/RGB_Out5: J2.10, LED5.4 (DIN)
/RGB_Out6: J1#2.10, LED6.4 (DIN)
/Row1: D1.1 (K), D1#2.1 (K), D6.1 (K), D11.1 (K), D16.1 (K), D21.1 (K), D26.1 (K), J1.6, J1#2.5, J2.5, J3.5, J4.5, J5.5, J6.5, J7.5, J8.6, J9.6, J10.6, J11.6, J12.6
/Row2: D2.1 (K), D2#2.1 (K), D7.1 (K), D12.1 (K), D17.1 (K), D22.1 (K), D27.1 (K), J1.7, J1#2.4, J2.4, J3.4, J4.4, J5.4, J6.4, J7.4, J8.7, J9.7, J10.7, J11.7, J12.7
/Row3: D3.1 (K), D3#2.1 (K), D8.1 (K), D13.1 (K), D18.1 (K), D23.1 (K), D28.1 (K), J1.8, J1#2.3, J2.3, J3.3, J4.3, J5.3, J6.3, J7.3, J8.8, J9.8, J10.8, J11.8, J12.8
/Row4: D4.1 (K), D4#2.1 (K), D9.1 (K), D14.1 (K), D19.1 (K), D24.1 (K), D29.1 (K), J1.9, J1#2.2, J2.2, J3.2, J4.2, J5.2, J6.2, J7.2, J8.9, J9.9, J10.9, J11.9, J12.9
/Row5: D5.1 (K), D10.1 (K), D15.1 (K), D20.1 (K), D25.1 (K), D30.1 (K), J1.10, J1#2.1, J2.1, J3.1, J4.1, J5.1, J6.1, J8.10, J9.10, J10.10, J11.10, J12.10
/V+: J1.2, J1#2.9, J2.9, J3.9, J4.9, J5.9, J6.9, J7.9, J8.2, J9.2, J10.2, J11.2, J12.2, LED1.1 (VDD), LED2.1 (VDD), LED3.1 (VDD), LED4.1 (VDD), LED5.1 (VDD), LED6.1 (VDD), SW1.+1 (VDD), SW1#2.+1 (VDD), SW2.+1 (VDD), SW2#2.+1 (VDD), SW3.+1 (VDD), SW3#3.+1 (VDD), SW4.+1 (VDD), SW4#2.+1 (VDD), SW5.+1 (VDD), SW6.+1 (VDD), SW7.+1 (VDD), SW8.+1 (VDD), SW9.+1 (VDD), SW10.+1 (VDD), SW11.+1 (VDD), SW12.+1 (VDD), SW13.+1 (VDD), SW14.+1 (VDD), SW15.+1 (VDD), SW16.+1 (VDD), SW17.+1 (VDD), SW18.+1 (VDD), SW19.+1 (VDD), SW20.+1 (VDD), SW21.+1 (VDD), SW22.+1 (VDD), SW23.+1 (VDD), SW24.+1 (VDD), SW25.+1 (VDD), SW26.+1 (VDD), SW27.+1 (VDD), SW28.+1 (VDD), SW29.+1 (VDD), SW30.+1 (VDD)
GND: J1.5, J1.S1, J1.S2, J1#2.6, J1#2.S1, J1#2.S2, J2.6, J2.S1, J2.S2, J3.6, J3.S1, J3.S2, J4.6, J4.S1, J4.S2, J5.6, J5.S1, J5.S2, J6.6, J6.S1, J6.S2, J7.6, J7.S1, J7.S2, J8.5, J8.S1, J8.S2, J9.5, J9.S1, J9.S2, J10.5, J10.S1, J10.S2, J11.5, J11.S1, J11.S2, J12.5, J12.S1, J12.S2, LED1.3 (GND), LED2.3 (GND), LED3.3 (GND), LED4.3 (GND), LED5.3 (GND), LED6.3 (GND), SW1.GND, SW1#2.GND, SW2.GND, SW2#2.GND, SW3.GND, SW3#2.2, SW3#2.4, SW3#3.GND, SW4.GND, SW4#2.GND, SW6.GND, SW7.GND, SW8.GND, SW9.GND, SW11.GND, SW12.GND, SW13.GND, SW14.GND, SW16.GND, SW17.GND, SW18.GND, SW19.GND, SW21.GND, SW22.GND, SW23.GND, SW24.GND, SW26.GND, SW27.GND, SW28.GND, SW29.GND
RESET: SW3#2.1, SW3#2.3

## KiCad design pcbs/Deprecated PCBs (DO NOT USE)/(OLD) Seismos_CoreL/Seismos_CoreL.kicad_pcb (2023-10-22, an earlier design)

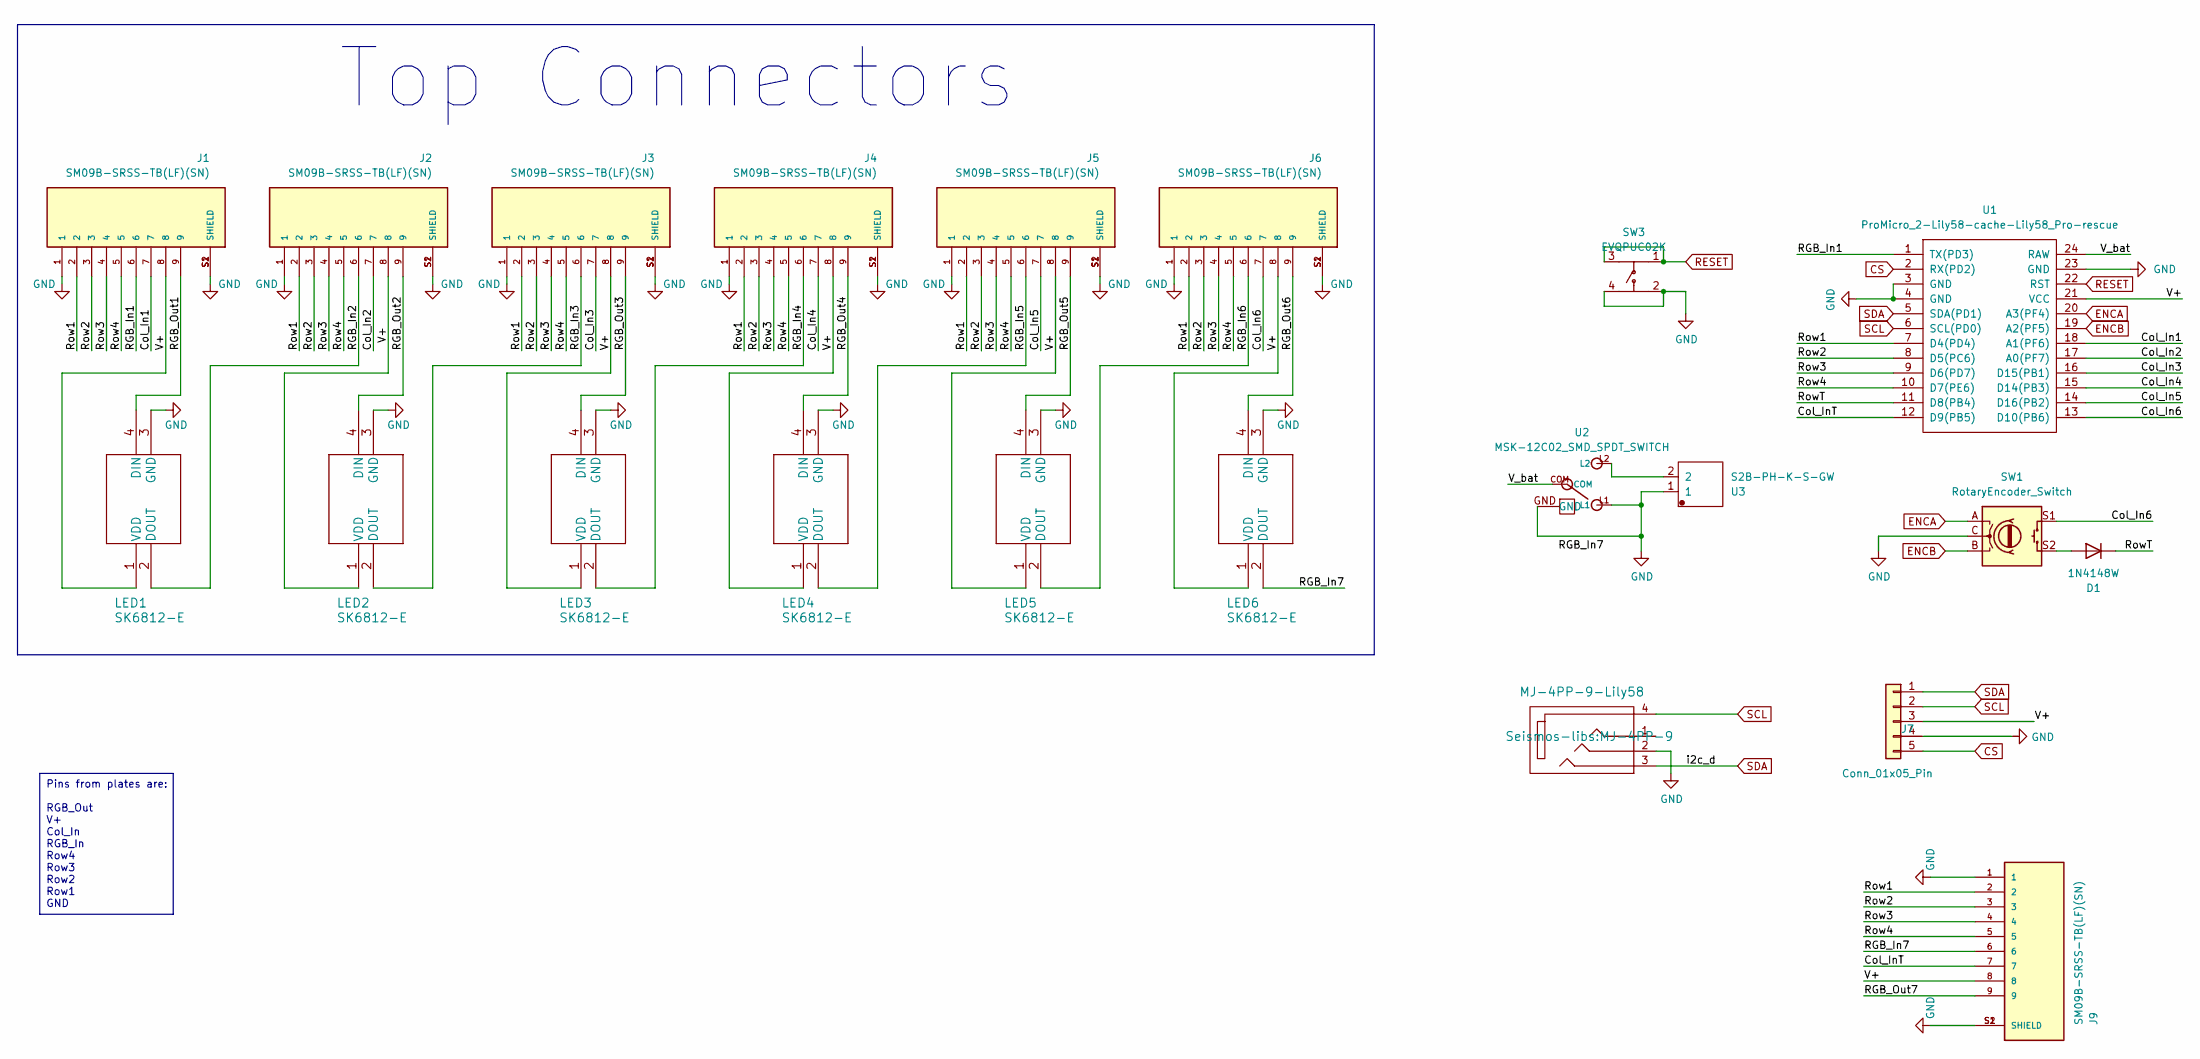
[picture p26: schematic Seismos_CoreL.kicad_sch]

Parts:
D1: 1N4148W; D_SOD-123
J1, J2, J3, J4, J5, J6, J9: SM09B-SRSS-TB(LF)(SN); JST_SM09B-SRSS-TB(LF)(SN); PARTREV 1.0
J7: Conn_01x05_Pin; PinHeader_1x05_P2.54mm_Vertical
J8: MJ-4PP-9-Lily58; MJ-4PP-9
LED1, LED2, LED3, LED4, LED5, LED6: SK6812-E
SW1: RotaryEncoder_Switch; RotaryEncoder_Alps_EC11E-Switch_Vertical_H20mm-keebio_modif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
SW3: EVQPUC02K; SW-SMD_EVQPUD02K
U1: ProMicro_2-Lily58-cache-Lily58_Pro-rescue; ProMicro
U2: MSK-12C02_SMD_SPDT_SWITCH; SW_PCM12SMTR
U3: S2B-PH-K-S-GW; CONN-TH_S2B-PH-K-S-GW

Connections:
/Col_In1: J1.7, U1.18 (A1(PF6))
/Col_In2: J2.7, U1.17 (A0(PF7))
/Col_In3: J3.7, U1.16 (D15(PB1))
/Col_In4: J4.7, U1.15 (D14(PB3))
/Col_In5: J5.7, U1.14 (D16(PB2))
/Col_In6: J6.7, SW1.S1, U1.13 (D10(PB6))
/Col_InT: J9.7, U1.12 (D9(PB5))
/RGB_In1: J1.6, U1.1 (TX(PD3))
/RGB_In2: J2.6, LED1.2 (DOUT)
/RGB_In3: J3.6, LED2.2 (DOUT)
/RGB_In4: J4.6, LED3.2 (DOUT)
/RGB_In5: J5.6, LED4.2 (DOUT)
/RGB_In6: J6.6, LED5.2 (DOUT)
/RGB_In7: J9.6, LED6.2 (DOUT)
/RGB_Out1: J1.9, LED1.4 (DIN)
/RGB_Out2: J2.9, LED2.4 (DIN)
/RGB_Out3: J3.9, LED3.4 (DIN)
/RGB_Out4: J4.9, LED4.4 (DIN)
/RGB_Out5: J5.9, LED5.4 (DIN)
/RGB_Out6: J6.9, LED6.4 (DIN)
/RGB_Out7: J9.9
/Row1: J1.2, J2.2, J3.2, J4.2, J5.2, J6.2, J9.2, U1.7 (D4(PD4))
/Row2: J1.3, J2.3, J3.3, J4.3, J5.3, J6.3, J9.3, U1.8 (D5(PC6))
/Row3: J1.4, J2.4, J3.4, J4.4, J5.4, J6.4, J9.4, U1.9 (D6(PD7))
/Row4: J1.5, J2.5, J3.5, J4.5, J5.5, J6.5, J9.5, U1.10 (D7(PE6))
/RowT: D1.1 (K), U1.11 (D8(PB4))
/V+: J1.8, J2.8, J3.8, J4.8, J5.8, J6.8, J7.3, J9.8, LED1.1 (VDD), LED2.1 (VDD), LED3.1 (VDD), LED4.1 (VDD), LED5.1 (VDD), LED6.1 (VDD), U1.21 (VCC)
/V_bat: U1.24 (RAW), U2.COM
CS: J7.5, U1.2 (RX(PD2))
ENCA: SW1.A, U1.20 (A3(PF4))
ENCB: SW1.B, U1.19 (A2(PF5))
GND: J1.1, J1.S1 (SHIELD), J1.S2 (SHIELD), J2.1, J2.S1 (SHIELD), J2.S2 (SHIELD), J3.1, J3.S1 (SHIELD), J3.S2 (SHIELD), J4.1, J4.S1 (SHIELD), J4.S2 (SHIELD), J5.1, J5.S1 (SHIELD), J5.S2 (SHIELD), J6.1, J6.S1 (SHIELD), J6.S2 (SHIELD), J7.4, J8.2, J9.1, J9.S1 (SHIELD), J9.S2 (SHIELD), LED1.3 (GND), LED2.3 (GND), LED3.3 (GND), LED4.3 (GND), LED5.3 (GND), LED6.3 (GND), SW1.C, SW3.2, SW3.4, U1.3 (GND), U1.4 (GND), U1.23 (GND), U2.GND, U2.L1, U3.1
unnamed: D1.2 (A), SW1.S2
unnamed: U2.L2, U3.2
RESET: SW3.1, SW3.3, U1.22 (RST)
SCL: J7.2, J8.4, U1.6 (SCL(PD0))
SDA: J7.1, J8.3, U1.5 (SDA(PD1))

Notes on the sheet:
Pins from plates are: RGB_Out V+ Col_In RGB_In Row4 Row3 Row2 Row1 GND
Top Connectors

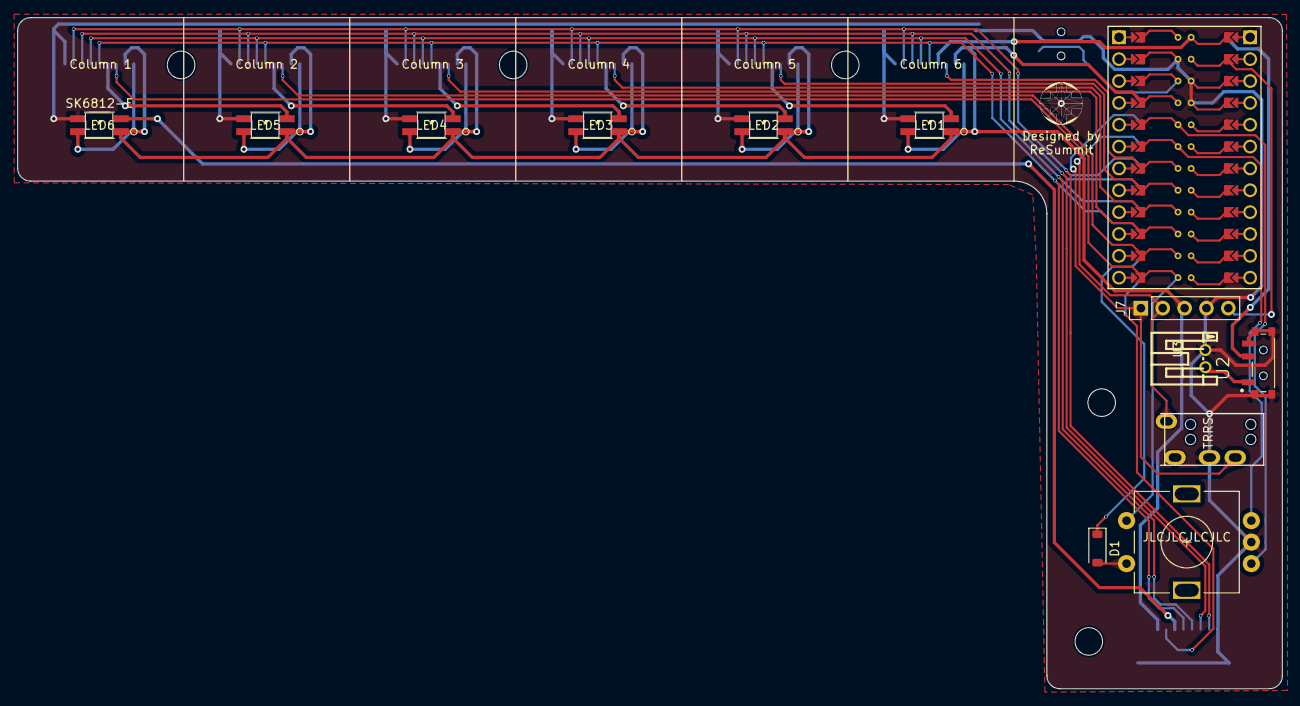
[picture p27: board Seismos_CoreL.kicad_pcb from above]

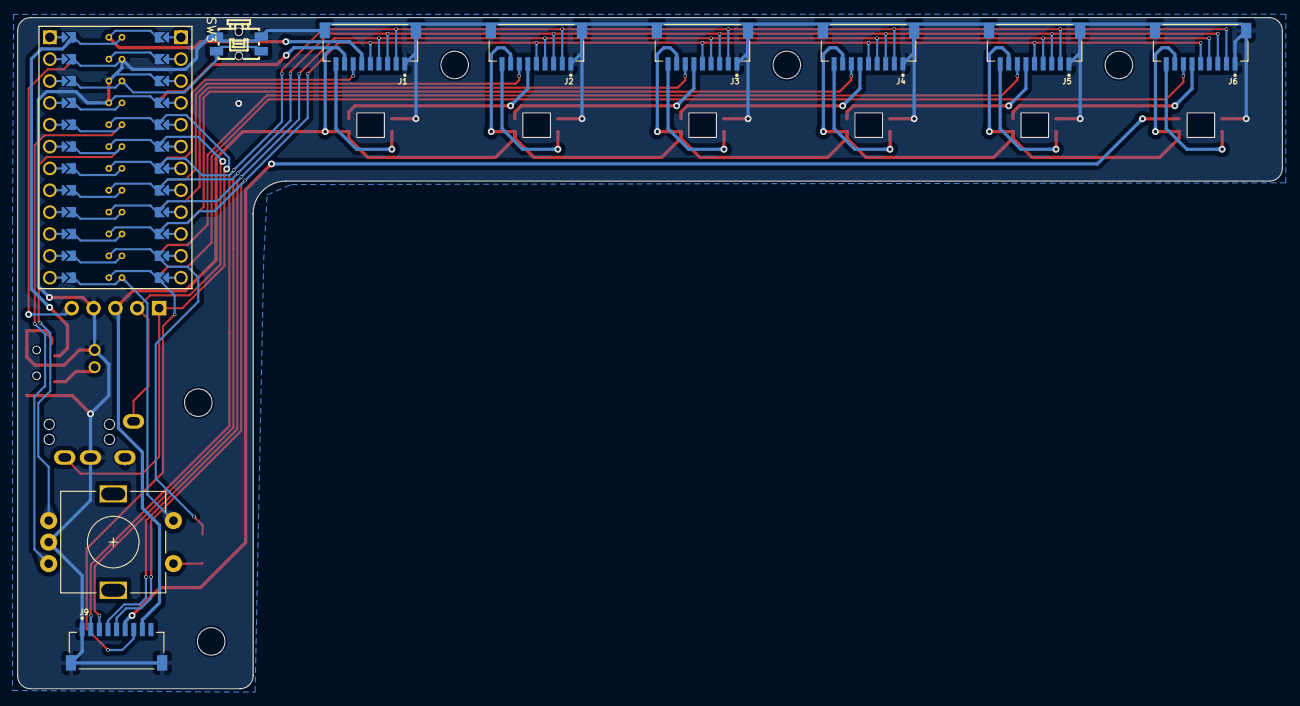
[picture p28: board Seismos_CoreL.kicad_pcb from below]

Board: 2 copper layers, 147.0 x 78.0 mm, 23 parts (14 on the bottom side), 36 nets.

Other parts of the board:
2, 4: Hole_M3_3.2mm

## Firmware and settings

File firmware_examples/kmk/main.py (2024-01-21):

print("Starting")

import board

from kmk.kmk_keyboard import KMKKeyboard
from kb import KMKCust
from kmk.keys import KC

from kmk.handlers.sequences import simple_key_sequence

from kmk.extensions.RGB import RGB
from kmk.extensions.rgb import AnimationModes
from kmk.extensions.media_keys import MediaKeys

from kmk.modules.layers import Layers

# I2C Pins
SCL=board.SCL
SDA=board.SDA

keyboard = KMKCust()
layers = Layers()
media_handler = MediaKeys()

keyboard.modules.append(Layers())
keyboard.extensions.append(MediaKeys())
 
keyboard.debug_enabled = False
keyboard.powersave_disable = True

# Key aliases
xxxxx = KC.NO
_______ = KC.TRNS

# Macro definitions
RAISE = KC.MO(1)
LOWER = KC.MO(2)
CTRA = KC.CTRL(KC.A)
CTRZ = KC.CTRL(KC.Z)
CTRX = KC.CTRL(KC.X)
CTRC = KC.CTRL(KC.C)
CTRV = KC.CTRL(KC.V)
VIMQA = simple_key_sequence((KC.COLN, KC.Q, KC.A, KC.ENT))
VIMRE = simple_key_sequence((KC.COLN, KC.PERC, KC.S, KC.PIPE, KC.PIPE, KC.PIPE, KC.G))

keyboard.keymap = [
    [
        KC.ESC,     KC.N1,      KC.N2,      KC.N3,      KC.N4,  KC.N5,      KC.D,                       KC.K,              KC.N6,      KC.N7,      KC.N8,      KC.N9,      KC.N0,      KC.BSPC,
        KC.GRV,     KC.Q,       KC.W,       KC.E,       KC.R,   KC.T,       KC.F,                       KC.J,              KC.Y,       KC.U,       KC.I,       KC.O,       KC.P,       KC.BSLS,
        KC.TAB,     KC.A,       KC.S,       KC.D,       KC.F,   KC.G,       KC.D,                       KC.K,              KC.H,       KC.J,       KC.K,       KC.L,       KC.SCLN,    KC.QUOT,
        KC.LSFT,    KC.Z,       KC.X,       KC.C,       KC.V,   KC.B,       KC.F,                       KC.J,              KC.N,       KC.M,       KC.COMM,    KC.DOT,     KC.SLSH,    KC.ENTER,
        KC.LCTL,    KC.LGUI,    KC.LALT,    KC.APP,     LOWER,  KC.SPC,     KC.AUDIO_MUTE,              KC.AUDIO_MUTE,     KC.SPC,     RAISE,      KC.LEFT,    KC.DOWN,    KC.UP,      KC.RGHT,

        # Encoders
        KC.AUDIO_VOL_UP,      #Left side clockwise
        KC.AUDIO_VOL_DOWN,    #Left side counterclockwise
        KC.AUDIO_VOL_UP,  #Right side clockwise
        KC.AUDIO_VOL_DOWN,  #Right side counterclockwise
    ],
    [
        _______,   KC.F1,   KC.F2,   KC.F3,   KC.F4,   KC.F5, _______,          _______,   KC.F6,   KC.F7,   KC.F8,   KC.F9,  KC.F10,   KC.DEL,
        _______,  KC.F11,  KC.F12, _______, _______, _______, _______,          _______, _______, _______, _______, _______, _______,  KC.PSCR,
        _______, _______, _______, _______, _______, _______, _______,          _______, _______, _______, _______, _______, _______,  _______,
        _______, _______, _______, _______, _______, _______, _______,          _______, _______, _______, _______, _______, _______,  _______,
        _______, _______, _______, _______, _______, _______, _______,          _______, _______, _______, _______, _______, _______,  _______,

        # Encoders
        KC.AUDIO_VOL_UP,      #Left side clockwise
        KC.AUDIO_VOL_DOWN,    #Left side counterclockwise
        KC.AUDIO_VOL_UP,  #Right side clockwise
        KC.AUDIO_VOL_DOWN,  #Right side counterclockwise
    ],
    [
        _______, _______, _______, _______,  _______,  _______, _______,          _______, _______, _______,  _______,  _______,  _______, _______,
        _______,   VIMQA, _______, _______,    VIMRE,  _______, _______,          _______, _______, _______,  _______,  _______,  _______, _______,
        _______, _______, _______, KC.LPRN,  KC.LBRC,  KC.MINS, _______,          _______,  KC.EQL, KC.RBRC,  KC.RPRN,  _______,  _______, _______,
        _______,    CTRZ,    CTRX,    CTRC,     CTRV,  _______, _______,          _______, _______, _______,  _______,  _______,  _______, _______,
        _______, _______, _______, _______,  _______,  _______, _______,          _______, _______, _______,  KC.HOME,  KC.PGDN,  KC.PGUP,  KC.END,

        # Encoders
        KC.AUDIO_VOL_UP,      #Left side clockwise
        KC.AUDIO_VOL_DOWN,    #Left side counterclockwise
        KC.AUDIO_VOL_UP,  #Right side clockwise
        KC.AUDIO_VOL_DOWN,  #Right side counterclockwise
    ],
]

rgb = RGB(
    pixel_pin=board.GP0,
    num_pixels=40,
    val_default=10,
    hue_step=5,
    sat_step=5,
    val_step=5,
    animation_speed=5,
    animation_mode=AnimationModes.SWIRL,
    reverse_animation=False,
    refresh_rate=60,
)

keyboard.extensions.append(rgb)
keyboard.extensions.append(media_handler)

if __name__ == '__main__':
    keyboard.go()

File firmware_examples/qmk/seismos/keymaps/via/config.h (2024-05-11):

/* Copyright 2023 Danny Vo
 *
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
 * You should have received a copy of the GNU General Public License
 * along with this program.  If not, see <http://www.gnu.org/licenses/>.
 */

#pragma once

/* By default left side is selected as master, 
see https://docs.qmk.fm/#/feature_split_keyboard?id=setting-handedness
for more options. */

#if defined(KEYBOARD_seismos)
// Add RGB underglow and top facing lighting
#    define WS2812_DI_PIN D3
#    define DYNAMIC_KEYMAP_LAYER_COUNT 5
#    define SERIAL_USART_FULL_DUPLEX
#    define SIDE_LEFT
#    if defined(SIDE_LEFT)
        #    define SERIAL_USART_TX_PIN F4
        #    define SERIAL_USART_RX_PIN F5
#    else
        #    define SERIAL_USART_TX_PIN F5
        #    define SERIAL_USART_RX_PIN F4
#    endif
// If your microcontroller supports it, you can detect the pin swap instead:
#    define SERIAL_USART_PIN_SWAP

#define BOOTMAGIC_LITE_ROW 0
#define BOOTMAGIC_LITE_COLUMN 0

//   Shift register for columns
#    define SHIFT_CS_PIN B6
#    define SHIFT_MOSI_PIN B2
#    define SHIFT_SCLK_PIN B1
#    define RGBLIGHT_LED_COUNT 70
#    define RGBLED_SPLIT \
        { 40, 40 }
#    define EE_HANDS
#    ifdef RGB_MATRIX_ENABLE
#        define RGB_MATRIX_LED_COUNT RGBLED_NUM
#        define RGB_MATRIX_SPLIT RGBLED_SPLIT
#        define SPLIT_TRANSPORT_MIRROR
#    else
#        define RGBLIGHT_EFFECT_BREATHING
#        define RGBLIGHT_EFFECT_RAINBOW_MOOD
#        define RGBLIGHT_EFFECT_RAINBOW_SWIRL
#        define RGBLIGHT_EFFECT_SNAKE
#        define RGBLIGHT_EFFECT_KNIGHT
#        define RGBLIGHT_EFFECT_CHRISTMAS
#        define RGBLIGHT_EFFECT_STATIC_GRADIENT
#        define RGBLIGHT_EFFECT_RGB_TEST
#        define RGBLIGHT_EFFECT_ALTERNATING
#        define RGBLIGHT_EFFECT_TWINKLE
#        define RGBLIGHT_LIMIT_VAL 120
#        define RGBLIGHT_HUE_STEP 10
#        define RGBLIGHT_SAT_STEP 17
#        define RGBLIGHT_VAL_STEP 17
#    endif
#endif

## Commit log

2023-10-15 Initial commit, add libs
    Add PCB files and files used for footprints and symbols
    Some symbols are derived from Lily58 and Corne but will update this in
    the README later.
    [Seismos_4-Key-B_Cu.gbl, Seismos_4-Key-B_Mask.gbs, Seismos_4-Key-B_Paste.gbp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]
2023-10-15 Create PCB STEP Files
    Generated STEP files.
    [Seismos_4PCB.step, Seismos_CoreL.step]
2023-10-15 Update 4Key Column STEP
    Wrong footprint definitions resulted in no parts shown so fixed it
    [Seismos_4-Key.kicad_pcb, Seismos_4PCB.step]
2023-10-17 Fix footprint errors and new 2x2 PCB
    Fixed keyboard_reversible.pretty not being included.
    Added a 2x2 PCB for the thumb.
    Added a note regarding DRC errors involving two specific footprints...
    [Seismos_4-Key-B_Cu.gbl, Seismos_4-Key-B_Mask.gbs, Seismos_4-Key-B_Paste.gbp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]
2023-10-17 Refresh Export of PCB
    [Seismos_4-Key-B_Cu.gbl, Seismos_4-Key-B_Mask.gbs, Seismos_4-Key-B_Paste.gbp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]
2023-10-17 Fix 4Key Column Hole Size
    Converted the M3 holes to the standard footprint instead of edge cut
    layer drawing of a circle. Also updated names of gerber output folders.
    [Seismos_4-Key-B_Cu.gbl, Seismos_4-Key-B_Mask.gbs, Seismos_4-Key-B_Paste.gbp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]
2023-10-17 Replaced microvias with very small vias
    Also added small JLCJLCJLCJLC text for JLCPCB.
    JLCPCB doesn't allow for blind microvias... so annoyingly I had to
    reroute the row and column wiring. Luckily the 4 key doesn't use
    microvias so that one is okay.
    [Seismos_CoreL-B_Cu.gbl, Seismos_CoreL-B_Mask.gbs, Seismos_CoreL-B_Paste.gbp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]
2023-10-17 Replaced microvias in CoreL
    I happened to find more... in CoreL only. CoreR looks mostly fine.
    [Seismos_CoreL-B_Cu.gbl, Seismos_CoreL-B_Mask.gbs, Seismos_CoreL-B_Paste.gbp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]
2023-10-18 Last look over CoreL and removed microvias
    CoreR has been verified by JLCPCB and is good to go. I forgot to add
    teardrops to it so it is now added. CoreL on the other hand had some
    more microvias near the JST SH conectors and under the rotary
    encoder. These have been removed.
    NOTE: Due to the microvia conversion, the previous commit was when the
    NTPH holes near the columns have been shifted down by 0.5 mm. This will
    be reflected in the case shortly but not yet as of now.
    We'll see what JLCPCB says but it looks okay; hopefully I will get
    results in a week or so.
    [Seismos_CoreL-B_Cu.gbl, Seismos_CoreL-B_Mask.gbs, Seismos_CoreL-B_Paste.gbp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]
2023-10-19 Update 3D PCB STEP models
2023-10-20 Completed Thumb 2x2 module
    [Seismos_4-Thumb-B_Cu.gbl, Seismos_4-Thumb-B_Mask.gbs, Seismos_4-Thumb-B_Paste.gbp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]
2023-10-22 5 key variant release!
    Well... thought 5 key variant would be a lot of work but it turns out
    that it isn't too much. This uses up ALL the pins on the arduino micro
    however and unfortunately, a 5 key version for the thumb isn't possible
    because one of the keys is used by the encoder.
    WARNING: This is NOT compatible with the 4 key version yet. This is
    specific to the column PCBs (4-Key and 4Thumb). In the next commit, I
    will fix this.
    [Seismos_4PCB.step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]
2023-10-22 Seismos PCB v1.0rc
    First preliminary release of PCB with support for 7 columns and 5 rows.
    Folders have now been restructured to organize between cores and mantles.
    Cores are the baseboard/motherboard of the keyboard.
    Mantles are the connections between the switches and the core.
    Of course, additional modules can be made for both cores and mantles.
    If you have more pins, larger modules are possible!
    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
    [Seismos_4-Key-B_Cu.gbl, Seismos_4-Key-B_Mask.gbs, Seismos_4-Key-B_Paste.gbp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]
2023-10-22 Update 3D models and upload gerbers
    [Seismos_4-Key.kicad_pcb, Seismos_4-Thumb.kicad_pcb, Seismos_4PCB.step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]
2023-10-22 JST SH cable text rearranged
2023-10-22 Make cable image bigger
2023-11-11 Added stencils for new and old PCBs
    Created stencils for solder pasting PCBs with the core and plates.
    I ordered both new and old versions so two stencils were made; however,
    the holes for the old variant are misaligned. For this, use the other
    aligning holes.
    In addition, repaired footprints for switches where the switch footprint
    was appearing on the reverse side. This is now fixed.
    [(OLD) Seismos_CoreStencil-B_Cu.gbl, (OLD) Seismos_CoreStencil-B_Mask.gbs, (OLD) Seismos_CoreStencil-B_Paste.gbp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]
2023-12-05 Modify case files and stencil, as well as fix thumb cluster
    [Mantle - Part 1.stl, Mantle - Part 2.stl, Mantle - Part 3.stl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]
2023-12-05 Release v1.1
    ***NOTE***: If you have a previous commit, please update your files.
    This commit fixes the incorrect RGB pinout and power switch as the
    RGB footprint was incorrect.
    The power switch behaviour is also fixed in this commit so the position
    matches on both sides.
    [Seismos_4-Key-B_Cu.gbl, Seismos_4-Key-B_Mask.gbs, Seismos_4-Key-B_Paste.gbp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]
2023-12-08 Update README
    Add specific BOM numbers that are needed for keyboard,
    plus suggestion for charlieplex columns and development pictures
2023-12-08 Fix schematic reference errors for thumb
    Errors appeared when applying thumb schematic to PCB.
    This doesn't change the PCB footprints though, so no re-release
    [Seismos_4-Thumb.kicad_pcb, Seismos_4-Thumb.kicad_sch]
2023-12-09 Release v1.1.1
    Added I2C pull up resistors and bridge contacts on the backif 5V power
    is desired. If you have v1.1, V+ is actually close to the headphone
    jack, so you can scratch off the trace and bridge there.
    [Seismos_5CoreL.kicad_pcb, Seismos_5CoreL.kicad_sch, Seismos_5CoreR.kicad_pcb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]
2023-12-09 Forgot to save, also update gerbers
    [Seismos_5CoreL-B_Cu.gbl, Seismos_5CoreL-B_Mask.gbs, Seismos_5CoreL-B_Paste.gbp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]
2023-12-27 Fix right encoder button, fix connector refs
    Right side encoder was still connected to the 6th column for some
    reason... Figures when you copy paste the same board design into a
    different project.
    Also fixed references for the SH connectors, so it doesn't look weird
    [Seismos_5CoreL-B_Cu.gbl, Seismos_5CoreL-B_Mask.gbs, Seismos_5CoreL-B_Paste.gbp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]
2023-12-27 Force upload updated gerbers
2023-12-27 Fix right side encoder mount to ground
    [Seismos_5CoreR-B_Cu.gbl, Seismos_5CoreR-B_Mask.gbs, Seismos_5CoreR-B_Paste.gbp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]
2024-01-06 Update README.md
    Nice!view displays are not nice at all (uses SPI instead of I2C)
2024-01-21 Added 74HC595A support, new release
    New PCB versions supporting shift register.
    Another JST SH connector is added to expose 2 spare pins.
    Footprints for microcontroller were updated using modified footprint from library.
    Original variants updated to these new footprints with some fixes as well.
    [Seismos_5CoreL-B_Cu.gbl, Seismos_5CoreL-B_Mask.gbs, Seismos_5CoreL-B_Paste.gbp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]
2024-01-21 Upload updated gerbers
2024-02-11 Add QMK firmware, fix extra IC ref on right
    [Seismos_5CoreRShift.kicad_pcb]
2024-05-02 HOTFIX, power switch bridges to ground
    [Seismos_5CoreL.kicad_pcb, Seismos_5CoreL.kicad_sch, Seismos_5CoreLShift.kicad_pcb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]
2024-05-03 Update PCB version and gerbers for HOTFIX
    [Seismos_5CoreL-B_Cu.gbl, Seismos_5CoreL-B_Mask.gbs, Seismos_5CoreL-B_Paste.gbp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]
2024-05-11 Add rhythm game module
    [Seismos_4-Rhythm-B_Cu.gbl, Seismos_4-Rhythm-B_Mask.gbs, Seismos_4-Rhythm-B_Paste.gbp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]

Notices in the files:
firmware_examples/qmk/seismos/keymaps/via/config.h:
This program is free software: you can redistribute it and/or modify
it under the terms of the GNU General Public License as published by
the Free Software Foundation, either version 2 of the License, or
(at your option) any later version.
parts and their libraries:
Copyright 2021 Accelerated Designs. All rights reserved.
